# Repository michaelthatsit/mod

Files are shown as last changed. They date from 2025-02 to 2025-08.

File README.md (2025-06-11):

#  Adept Anyball

[Ploopy Adept](https://ploopy.co/adept-trackball) mod for 8 mm BOSCH Rexroth <a href='#btus-needed'>BTUs</a> with optional <a href='#magnets'>magnetically</a> attachable buttons. \
Various adapters are available, making it possible to use not just BTUs but also default ball bearings, static bearings. 



## Compatibility<sup>\*</sup>

| Ball | | |
| --- | --- | --- |
| 34 mm, 38.1 mm | ✔️  | e.g. Perixx, original Ploopy Nano ball; see [this repo](https://github.com/adept-anyball/ploopy-adept-small-btu) |
| 44 mm | ✔️  | e.g. from ProtoArc, JOMAA |
| 45 mm | ✔️  | default Adept ball |
| 50.8 mm | ✔️  | english pool ball, from Adesso T50 |
| 52.4 mm | ✔️  | snooker ball |
| 55 mm | ✔️  | e.g. from Kensington Expert, Perixx |
| 57 mm | ✔️  | pool ball |
| 60 mm | ✔️  | pool ball |
| 68 mm <sub>?!</sub> | ✔️  | russian<sup>\*\*</sup> pyramid ball |

<sup>\*chances are your ball is compatible if it's within the \[min, max\] range, and it probably is.</sup> \
<sup>\*\*kindly consider [supporting Ukraine](https://u24.gov.ua) to fight Russia in the ongoing invasion and occupation.

## General tips

> ❗️ **Important!** \
> \
> Use STL (not STEP) files for Slic3r forks, i.e. Prusa-, Orca-, Bambu Slicer. 
> STEPs are for CADs. There has been many cases reported when a STEP file has caused invalid geometry, 
> including critical changes such as "no gap between button and shell".

### Printing

1. There MUST be no supports, unless you really know what you are doing.

2. PLA, PETG, ABS — any of those are fine. 

### Other

1. Insert magnets on a flat hard surface while the device is not assembled.

2. Cyanoacrylate (superglue) works nice for magnets.

3. If you experience buttons sticking, try loosening the screws or removing the sensor cover.

4. If you experience bad tracking, you may want to print and install spacers.

## 57-68 mm ball (or 50-60 mm with spacers installed)

<p>
  
  
</p>

## 50-55 mm ball

Also available for non-standard BTUs: 
[SP-8](https://github.com/adept-anyball/mod/issues/5), [Veichu-15](https://github.com/adept-anyball/mod/issues/11).

> If you use CY-8H Aliexpress BTUs, it is recommended to go with the 50-52.4mm version instead. \
> You can ignore the fact that it is deprecated in such a case. \
> That version (in combination with this BTUs) should work with a 55 mm ball too.

<p>
  55mm ball
  55mm ball
</p>

## 50-55 mm ball (short version)

Fits a 50-55 mm ball. In this mod, the bottom and top parts of the original Adept case have been modified.

<p>
  55mm short top
  55mm short side
</p>

## 50-55mm ball (short, thin bezel)  
Fits a 50-55 mm ball. In this mod, the bottom and top parts of the original Adept case have been modified.  
It was built based on the short version above.
<div style="display: flex; justify-content: space-between; align-items: center;">
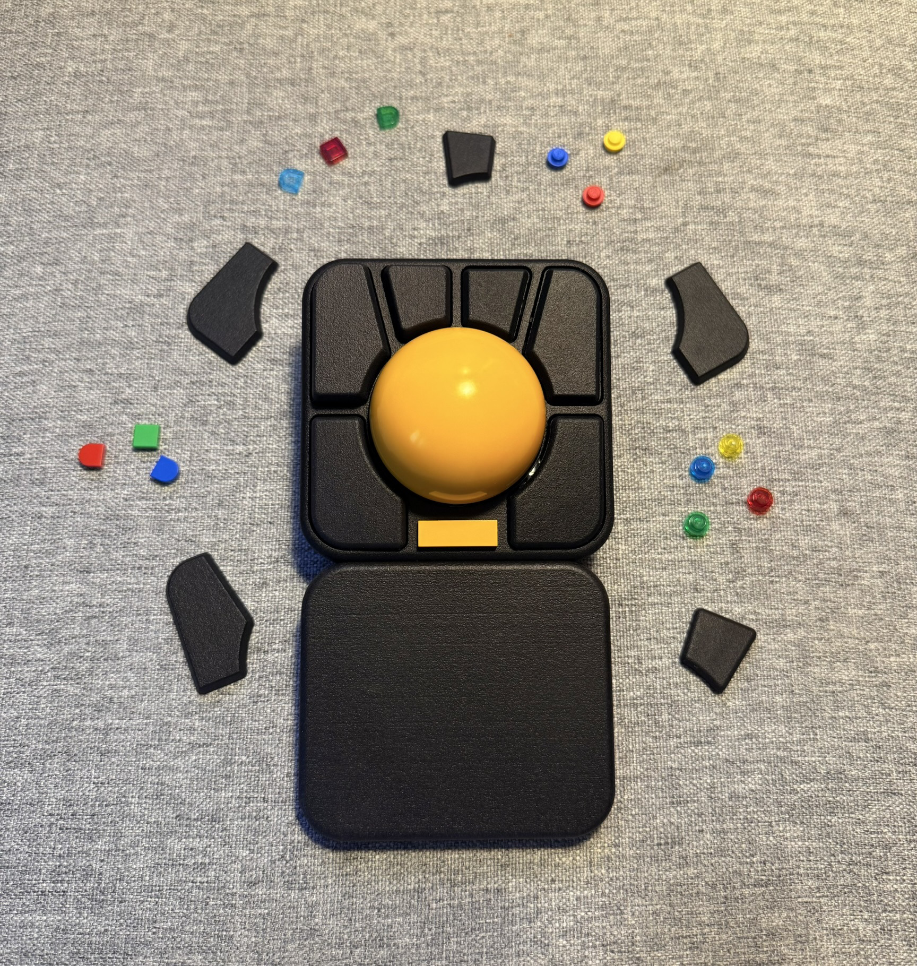
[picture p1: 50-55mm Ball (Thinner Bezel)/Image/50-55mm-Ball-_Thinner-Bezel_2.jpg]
Side View
  
  Close-up View
</div>

## 44-45 mm ball

This mod fits the original 45mm ball. \
You can find the 3MF files for Bambu printers on [Makerworld](https://makerworld.com/en/models/1087275#profileId-1080219).

<p>
  45mm top
  45mm top without ball
</p>

## 50-52.4 mm ball _DEPRECATED_

> The shell is deprecated, see 50-55mm one. It has standard size buttons and better BTUs placement.

<p>
  
  
</p>

## BTUs needed

[This is the link](https://store.boschrexroth.com/BALL-TRANSFER-UNIT_R053010810) to genuine BOSCH Rexroth BTUs.

<p>
  BTU specsheet
</p>

CY-8H BTUs from AliExpress [are compatible](https://github.com/adept-anyball/mod/issues/6), with one exception so far. \
[SP-8](https://github.com/adept-anyball/mod/issues/5) and [Veichu-15](https://github.com/adept-anyball/mod/issues/11) are not directly compatible, but there are model(s) available. \
Rexroth BTUs are clearly superior and are highly recommended.

## Magnets

You will need 4x2 mm circular neodymium magnets, full set (device + buttons) is 24pcs. \
They MUST be glued, ideally with a cyanocrylate based glue. 

## Quality Assurance

We have the best of the best.



## Even more photos

See [gallery](https://github.com/adept-anyball/mod/issues/7).

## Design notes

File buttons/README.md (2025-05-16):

# Buttons

The buttons in this folder are [ISO-2025EFOG](https://github.com/efogdev/ISO-2025EFOG) compliant and are compatible with the mods that follow the standard. The shape and size are absolutely identical to the default Ploopy buttons.

## Spherical 5mm

5 mm tall with a 2 mm deep spherical cut:

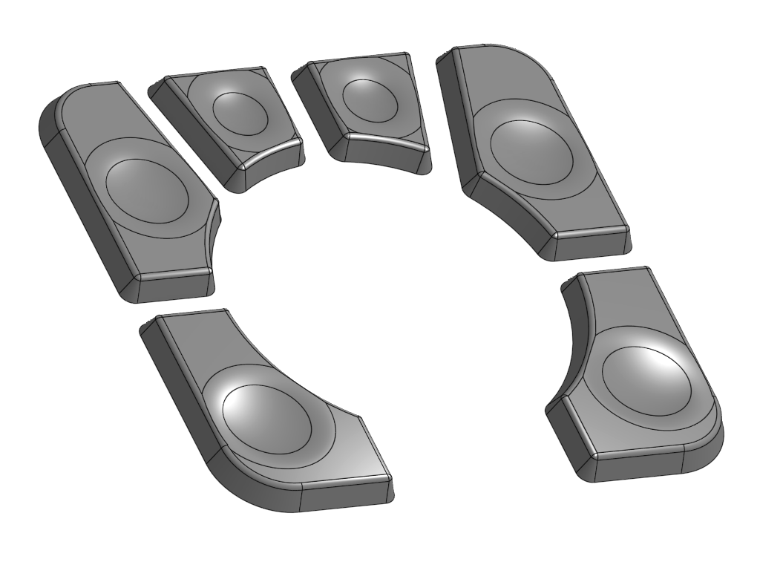
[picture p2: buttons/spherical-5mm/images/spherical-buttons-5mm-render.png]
spherical-5mm


## Flat 5mm

5 mm tall flat buttons

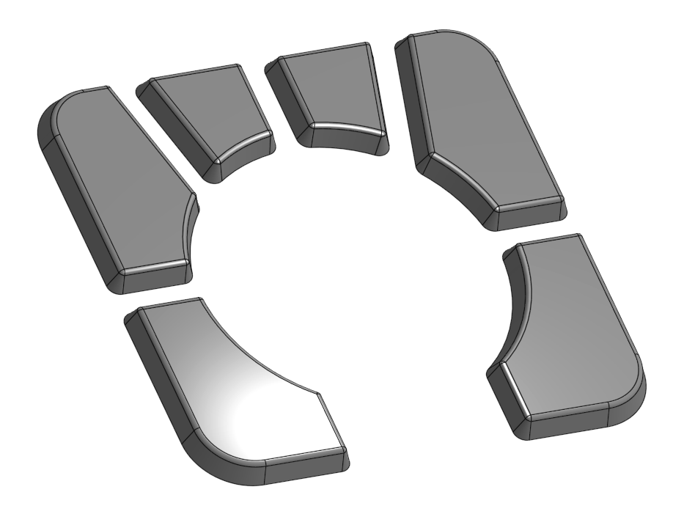
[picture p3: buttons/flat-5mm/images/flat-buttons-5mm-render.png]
flat-5mm


## Default

The default style buttons will look like this:



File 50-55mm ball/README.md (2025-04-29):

## Adept + 50-55mm ball

> ✅ [ISO-2025EFOG](https://github.com/efogdev/ISO-2025EFOG) compliant

> ❗️ It has been reported that CY-8H Aliexpress BTUs don't work with this version well. 

## Everything?

Everything. Even the sensor cover, the bottom part, the "default" buttons. \
**You need to split those in your slicer before printing.** \
The bottom part is optional and is 100% compatible with the default Ploopy bottom.

A [public third-party Onshape document](https://cad.onshape.com/documents/8ccfa9641ddd3f6929d9303b/w/a0d313c8d0288c4ecea783e6/e/e5fdbae89a3f2a2f05d6562c
).

## FAQ

Q: Layer height? \
A: Use 0.1-0.12mm for the buttons and 0.2mm for everything else.

Q: Where are other buttons? \
A: [Here](https://github.com/adept-anyball/mod/tree/master/buttons).

Q: I don't have magnets, is it usable? \
A: Yes, it is very usable even with magnets not inserted. 

Q: 57mm ball pretty please??? \
A: Might work with 0.4mm spacers. I haven't tried that. 

Q: Why is the bottom part even here? \
A: It is 1.2mm lower but has the sensor chip exposed. It is recommended to cover the hole with any tape. 

Q: top-for-non-standard-*-BTUs.stl \
A: Pretty self-explanatory, isn't it? You can also go to the issues to find a relevant thread. Please make sure to "split to object" in your slicer before printing.

## Demo



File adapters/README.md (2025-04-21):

## Adapters

This folder contains various adapters. \
Most work best with TPU, but PETG and PLA are also fine.

### Veichu

Allows Veichu 7.5mm BTUs to be used instead of Rexroth ones. \
Not recommended for >50mm balls. \
[Github issue](https://github.com/adept-anyball/mod/issues/4)

### Static

[Github issue](https://github.com/adept-anyball/mod/issues/8)

#### 3-3.5mm

Allows static bearings of size 3-3.5mm to be installed (with glue). \
Not recommended for heavy balls.

#### 2.5mm, 3mm and 3.5mm (no glue - 2 pieces)

Allows static bearings of 2.5mm, 3mm or 3.5mm to be installed (choose the correct file according to the size of the bearing)

> This adapted consists of 2 parts, so make sure to split it in your slicer. \
> This adapter requires no supports to be printed. \
> The 3mf for the 2.5mm is included too, if you have a Bambu Labs printer. It is recommended to print with a layer height of .1mm and width of .3mm, since the parts are small.

> **DISCLAIMER: Since I don't have any 3mm or 3.5mm static bearing at hand, then these 2 models are untested for the time being.**

To use it, insert the bearing ball in the bottom of the adapter. Slide the bottom part in the top part and turn the bottom to lock.

<p>
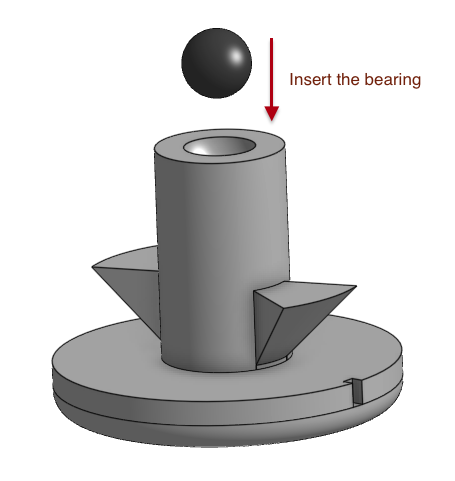
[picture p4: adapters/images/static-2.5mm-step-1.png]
  
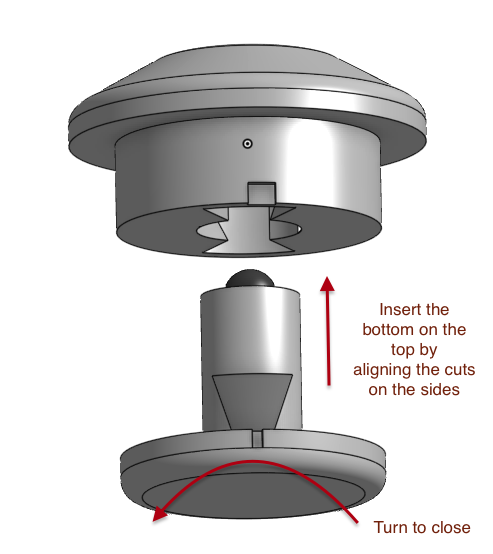
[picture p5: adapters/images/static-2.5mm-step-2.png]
  
</p>

### MR63 ball bearings

Allows default Ploopy MR63 ball bearings to be installed. \
[Github issue](https://github.com/adept-anyball/mod/issues/22)

## Notes

Please print adapters oriented like this:



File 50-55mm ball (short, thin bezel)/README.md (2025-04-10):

 # 50-55mm ball (short, thin bezels)
50-55mm Ball Side Preview
> ✅ [ISO-2025EFOG](https://github.com/efogdev/ISO-2025EFOG) compliant

This mod is an adaptation of the original case where the top and bottom of the original adept are changed. The optics cover (bottom of the top case) is the same as the original.
The mod is designed for a 55mm ball, but works with 50-55mm balls.

> Note from [@efogdev](https://github.com/efogdev): \
> This is a community contribution from [@Dexter-KBD](https://github.com/Dexter-KBD).
> As the owners of the Anyball repo can't directly provide support with this variant,
> please make sure to tag [@Dexter-KBD](https://github.com/Dexter-KBD)
> when creating an issue/discussion related to it.

Disclaimer
====================
Since English is not my native language, this post was translated with the help of ChatGPT. Thank you for your understanding.
If there's anything unclear or if you have any questions, feel free to join [Ploopy Discord channel](https://discord.com/invite/qYK9psKrNY)
 and ask anytime.

<br>

About This Model
====================
50-55mm Ball Preview

This design is a modified version based on the 55mm short version originally created by [@fabriciobastian](https://github.com/fabriciobastian)
  
I’d like to express my sincere thanks to [@fabriciobastian](https://github.com/fabriciobastian) for creating such a great model.  
[50-55mm ball (short version)](https://github.com/adept-anyball/mod/tree/master/50-55mm%20ball%20(short%20version))  

BOSCH Rexroth BTUs must be used. 
I haven't tried anything else, but looking at users' reviews, it's terrible. Buy BOSCH Rexroth BTUs. 
I bought it on [this site](https://www.robaraindustries.com/en/product/42563/ball-transfer-units-r053010810-ku-b8-ofk-rex.html)
 (it took me 3 weeks with the cheapest shipping option)
<br>

About the LEGO-Compatible Case
====================
The case with LEGO brick mounts was designed specifically for 3D printing using PA12 MJF material.
This structure relies on MJF’s powder-based printing method to be printed properly.
(If you're not sure what that means, I recommend watching a YouTube video showing how MJF printing works.)

Because of this, using this file with FDM printing will require support structures.
Since I don’t have in-depth knowledge of 3D printing, I wasn’t able to figure out a way to print this model without supports.
So, I have also included a modified version optimized for FDM printing that does not require support.
<br>

FDM-Specific Versions
====================
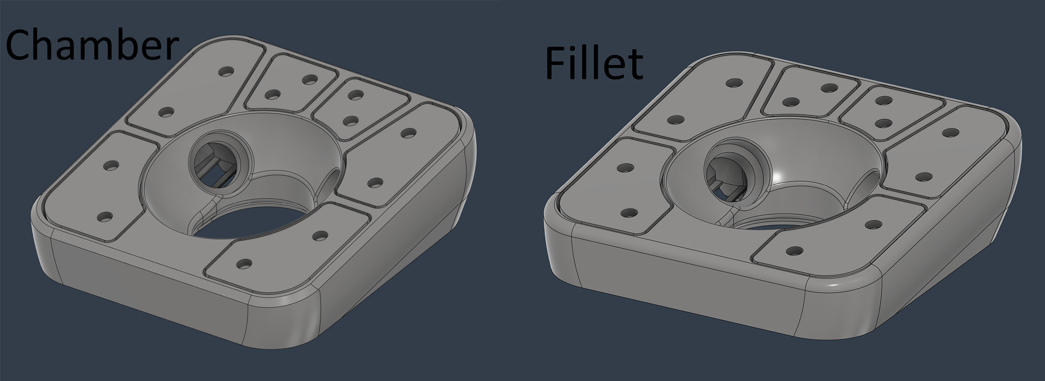
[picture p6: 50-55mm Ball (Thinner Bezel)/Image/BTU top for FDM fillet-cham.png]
BTU Top for FDM (Fillet/Chamfer)


To help ensure better print quality with FDM, I’ve included two versions:
one with chamfered corners and one with filleted edges.
I haven’t tested which one prints better, so it’s entirely up to you to choose.
<br>

Spring Adjustments for MJF
====================
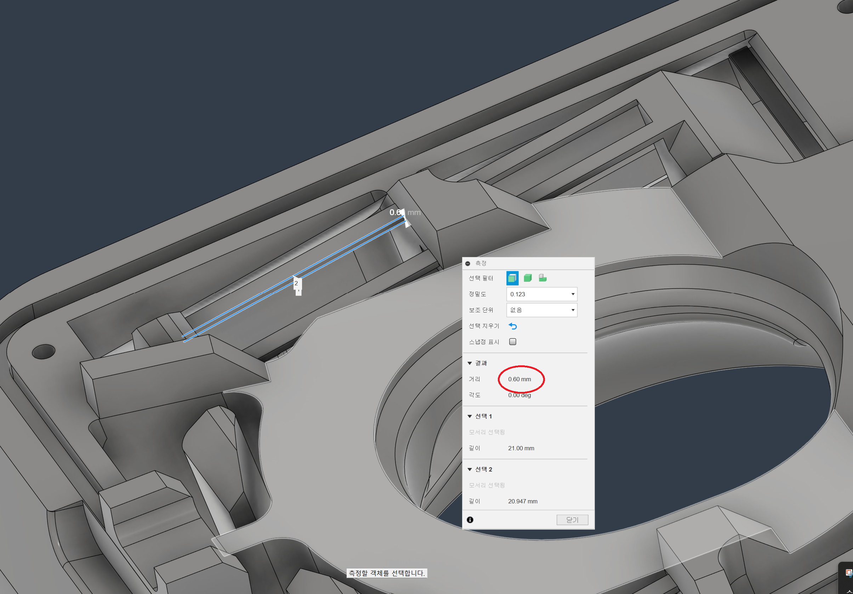
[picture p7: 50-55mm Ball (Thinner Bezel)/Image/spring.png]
Spring Detail


Since MJF materials are more flexible, I’ve increased the thickness of the button spring from 0.6mm to 1.2mm.
There are also a few other minor adjustments to help prevent damage during MJF post-processing.
<br>

FDM Version Details
====================
The FDM version keeps the original 0.6mm spring design.
Also, the pillar that holds the LEGO brick was removed to allow the surface to be printed facing down, resulting in better quality.
<br>

Palm Rest (Bonus)
====================
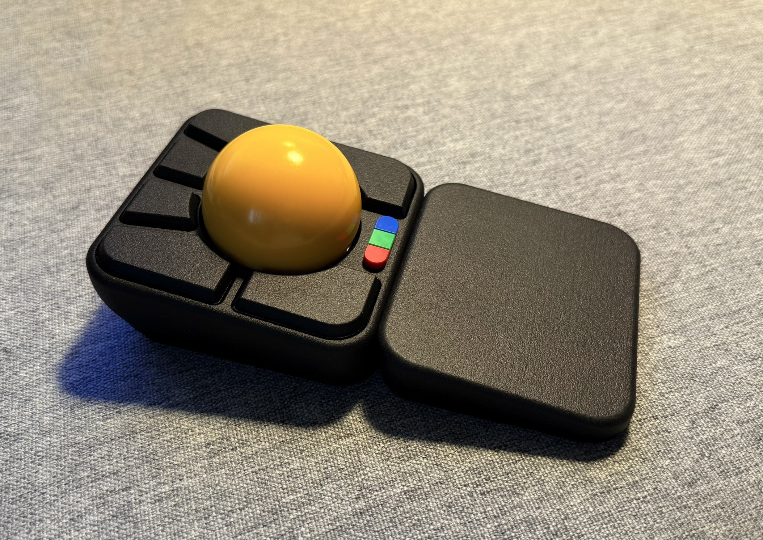
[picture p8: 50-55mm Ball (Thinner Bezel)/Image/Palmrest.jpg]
Palmrest Preview

I’ve also included a palm rest, just in case anyone finds it useful.
It was a quick 10-minute design, so I wasn't sure whether to share it, but I uploaded it anyway.
Since it was printed with MJF, there is a hole at the bottom.

It can be too short or too narrow because it's tailored to my hand.  
Make sure to check the size.  
It measures 92.7mm by 79mm.  
The height matched the case.  
<br>

Final Note
====================
Once again, please note that I have never printed this model using FDM materials.
This version simply shares the same design with a modified 0.6mm spring thickness.
Unexpected issues may arise.
If you enjoy experimenting, feel free to try printing with my file.
But if you prefer a well-tested and stable version, I recommend using one of the existing mods.
  
Thank you!

50-55mm Ball Close-up

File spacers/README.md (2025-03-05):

## BTU Spacers

> Works best with TPU. PLA/PETG is fine too.

Possible reasons to print a spacer or several:
1) Your ball touches the shell while rolling.
2) You want to use a smaller ball than the shell allows.
3) Your particular ball doesn't work well even though the shell supports it's size.

In either case, spacers may help. Or may not. Example usage:



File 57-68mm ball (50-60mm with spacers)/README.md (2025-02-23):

## Adept + 57-68 mm ball

> ❗️ not [ISO-2025EFOG](https://github.com/efogdev/ISO-2025EFOG) compliant

## Spacers

You need spacers for 50-56.5mm balls, see the README in the directory.

## FAQ

Please refer to [the README](https://github.com/adept-anyball/mod/tree/master/50-52.5mm%20ball%20(deprecated)/README.md) for 50-52.5 mm ball. \
Main differences: there is no smooth version, there is no version without magnets (I don't think it makes sense). \
The recommended buttons are D850 Hn6 (Hn = H<sub>negative</sub>, see [this README](https://github.com/adept-anyball/mod/blob/master/buttons/default/README.md)). 
> Tip: scale the logo in slicer if it doesn't fit. \
> Extra tip: print logo parts in several sizes (95%, 100%, 105%) as the shell has holes to extract those and you can switch ±easily (you still need to disassemble the Adept tho).

## Demo





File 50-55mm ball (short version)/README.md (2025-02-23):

# Adept 50-55mm ball (short version)

<p>
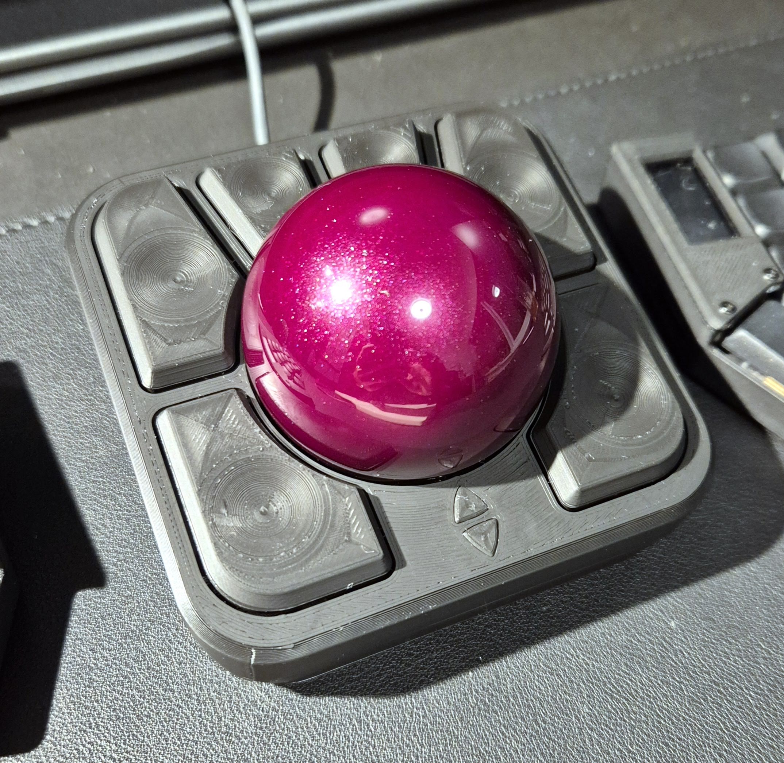
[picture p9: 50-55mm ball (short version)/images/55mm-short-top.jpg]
55mm short top
  
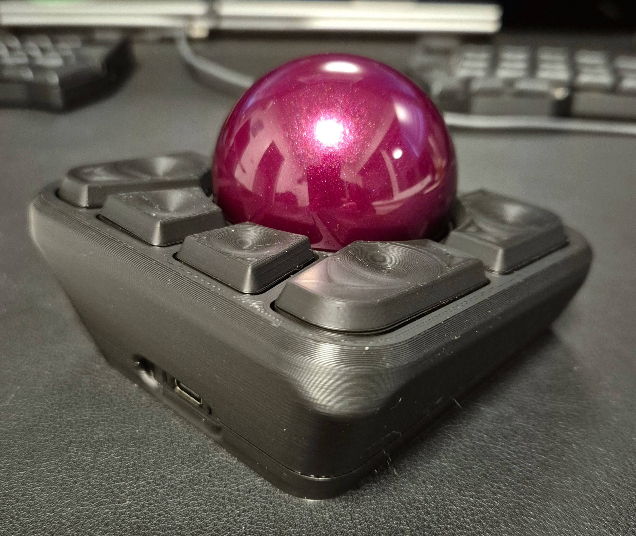
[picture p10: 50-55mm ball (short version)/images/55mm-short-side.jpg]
55mm short side
  
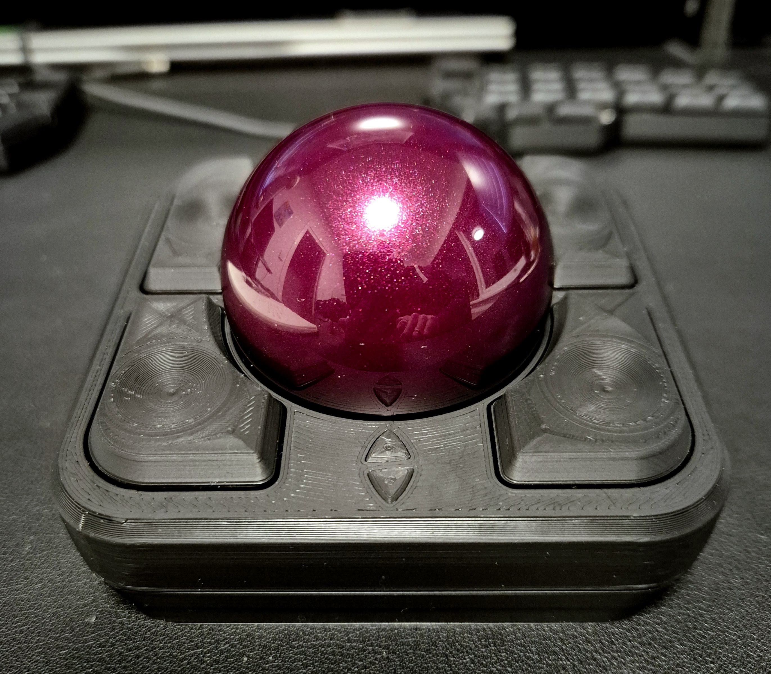
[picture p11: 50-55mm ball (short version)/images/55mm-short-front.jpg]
55mm short front
  
</p>

> ✅ [ISO-2025EFOG](https://github.com/efogdev/ISO-2025EFOG) compliant

This mod is an adaptation of the original case where the top and bottom of the original adept are changed. The optics cover (bottom of the top case) is the same as the original.
The mod is designed for a 55mm ball, but works with 50-55mm balls.

The following files are available in both STEP and STL:

- top-short-55mm: the top of the case without magnet holes
- top-short-55mm-magnets: the top of the case with magnet holes
- bottom-short: the bottom of the case. The bottom of the short mod is the same for the 55mm and 45mm, it is just available here too for convenience
- logo-insert-short: insert for the logo. It can be printed in different colors, if desired

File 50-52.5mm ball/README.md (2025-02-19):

## Adept + 50-52.5 mm ball

> ❗️ not [ISO-2025EFOG](https://github.com/efogdev/ISO-2025EFOG) compliant

## FAQ
Q: `rev1` or `rev2`? \
A: `rev2` 

Q: What does "50-52.5 mm" mean? \
A: `rev1` is compatible only with 50 mm ball, `rev2` should work with any diameter within the range.

Q: What's with the "bottom" and "sensor-cover"? \
A: Sensor cover is required to print. Bottom is the bottom part but slightly lower, it is optional.

Q: Can I print "magnets" version if I don't have magnets yet? \
A: Yeah it actually is very usable even with magnets not inserted.

Q: Do I need to populate all the 11 magnets for the wrist rest? \
A: I believe 5 should be enough. You can try as low as 3 tho.

Q: STEP or STL? \
A: I recommend using STL for slicer and STEP for CAD.

## Layer height
1. Top (Smooth), buttons, wrist rest: 0.1-0.12 mm
2. Top (Sharp), other: 0.1-0.2 mm

## `Flat` vs `Magnets`
Flat version is just like the default one. \
The one marked as "magnets" includes slots for magnets to attach raised buttons and wrist rest. \
Magnets required: 4x2 mm, 24 pcs for the buttons and 3/5/7/11 pcs for the wrist rest. \
Demo with buttons attached: 



## `Sharp` vs `Smooth`
55mm

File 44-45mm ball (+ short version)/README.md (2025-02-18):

## Adept + 44-45mm ball

> ✅ [ISO-2025EFOG](https://github.com/efogdev/ISO-2025EFOG) compliant

Q: Layer height? \
A: 0.2 mm

Q: What is the standard mod? \
A: It is the original case modified top fit the BTUs. All you need is to reprint the top part. For more info, see [here](./standard/README.md).

Q: What is the short mod? \
A: It is a slightly smaller mod, where both the top and the bottom of the case are changed. The blank space at the end of the top of the original case is remove, and the bottom part is aligned with the top (in the original it is smaller). \
For more info, see [here](./short/README.md). \
This is how it looks: \
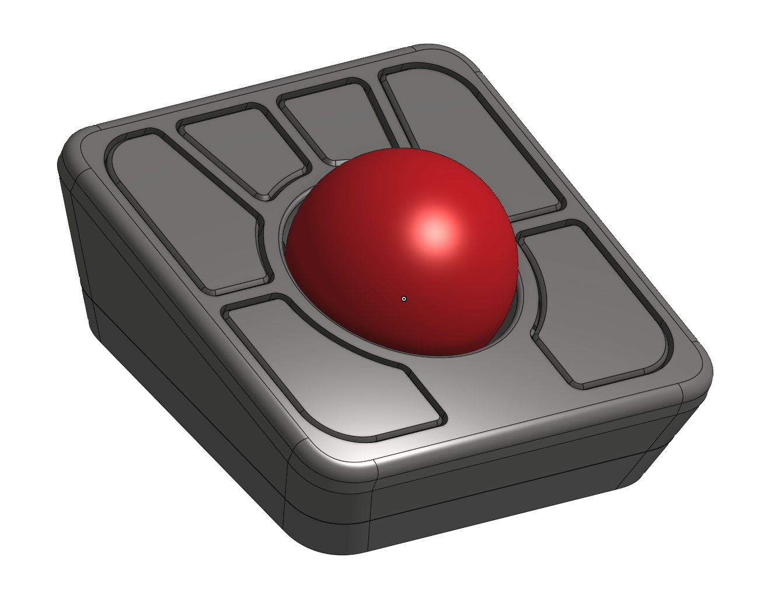
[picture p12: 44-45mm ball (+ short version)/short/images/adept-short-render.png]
45mm short


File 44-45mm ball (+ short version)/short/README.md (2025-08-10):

# Adept 44-45mm short mod

This model is changes both the top and the bottom of the case. The optics cover it still compatible with the original one.
The main differences from this mod and the original case is that it is slightly shorter and the top and bottom are aligned. In the original model, the bottom is smaller then the top. The case is designed to fit the original 45mm pool ball, but it should also work with a 44mm ball.

45mm short

The following models are available here:

- bottom-short-45mm: the bottom of the case
- top-short-45mm-magnets: the top part of the case with holes for the 4x2mm magnets and complies with ISO-2025EFOG
- top-short-45mm: the top of the case without any holes for magnets

Both models have STEP and STL files for you to choose between.

## AdeptBLE Short

This version is modified to support the [adept BLE mod](https://github.com/taichan1113/AdeptBLE). It includes room for a battery and a convenient switch hole and cover.

the battery cavity was shaped to [fit this battery](https://www.amazon.com/dp/B095VW1RB8?ref=ppx_yo2ov_dt_b_fed_asin_title&th=1) which can be found on amazon.

The top was modified slightly to avoid pressing down on the pins soldered into the board.

the following models are meant for the adept BLE short:

- bottom-short-battery: included the bottom plate and switch cover
- top-short-battery: includes the slightly modified top

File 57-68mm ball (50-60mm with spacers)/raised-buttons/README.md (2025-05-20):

## Buttons

Please see [this README](https://github.com/adept-anyball/mod/tree/master/buttons/default) for explanation.

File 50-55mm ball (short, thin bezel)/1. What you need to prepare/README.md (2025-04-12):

# Beginner Guide: What You Need to Prepare for the Ploopy Adept Mod

## 1. Ploopy Adept PCB
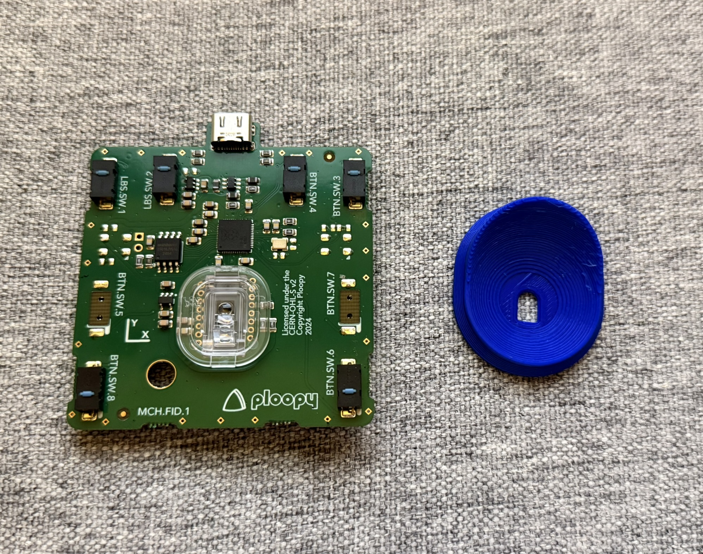
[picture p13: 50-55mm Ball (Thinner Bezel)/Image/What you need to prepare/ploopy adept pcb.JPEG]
Ploopy Adept PCB
   

You can either purchase a [fully assembled version](https://ploopy.co/shop/adept-trackball-fully-assembled/)
 from the official Ploopy website or build one yourself using the [open-source files](https://github.com/ploopyco/adept-trackball/tree/master/hardware/electronics)
. If you're a beginner and unfamiliar with soldering or hardware, I recommend buying the prebuilt version. If you're an experienced builder, you probably don’t need my advice.

## 2. Case for the Mod
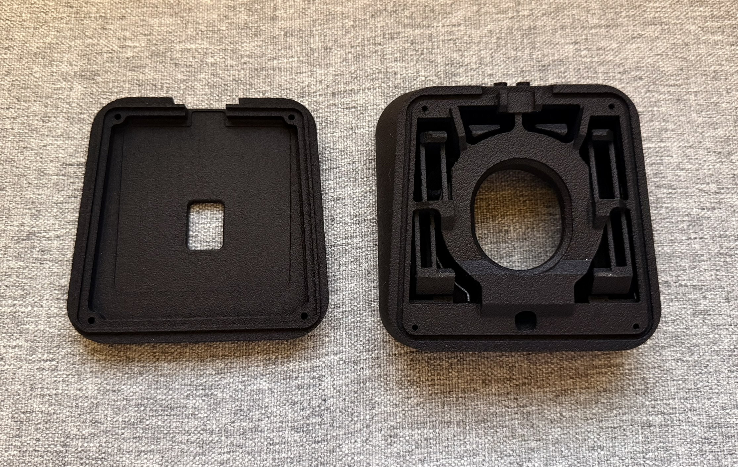
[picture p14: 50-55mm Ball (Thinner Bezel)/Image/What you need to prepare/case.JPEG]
Case for the Mod


You need only the top and bottom parts. The original sensor cover is reused. If you're not buying the prebuilt version from the official site and are instead building your own PCB, you will also need the sensor cover. (It's mainly for dust protection, so the device will still function without it.)

## 3. Buttons
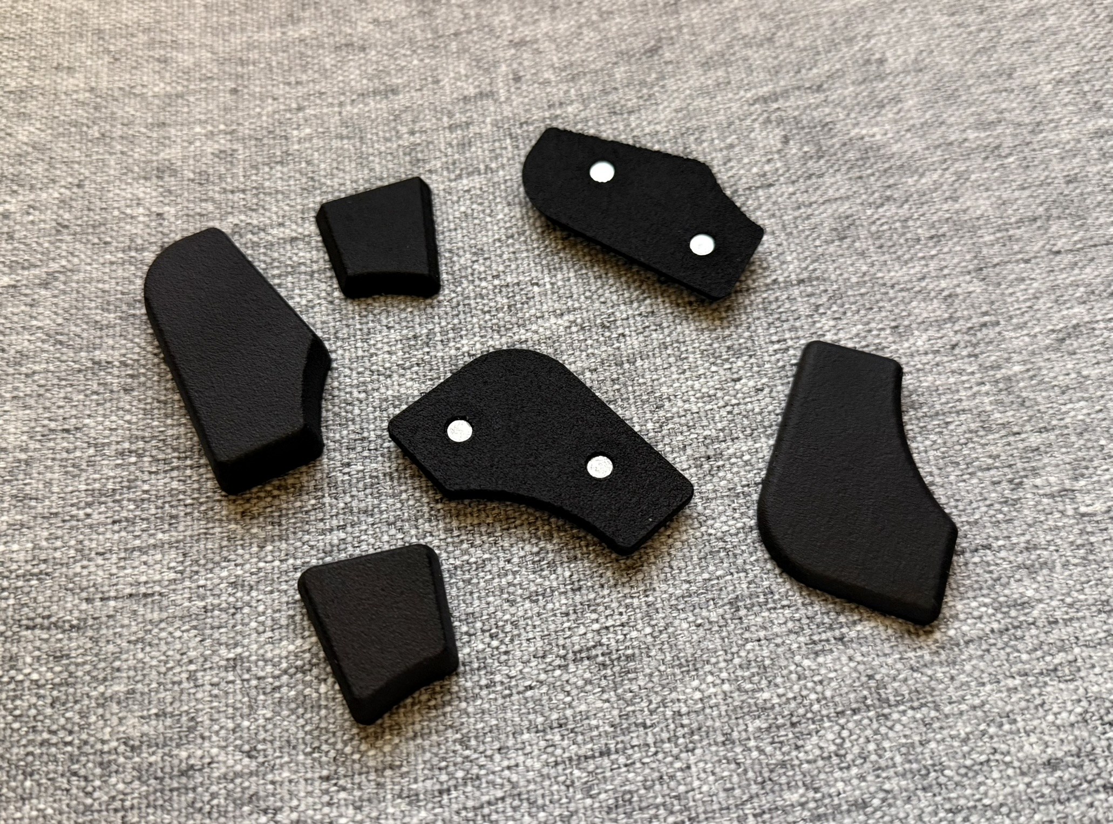
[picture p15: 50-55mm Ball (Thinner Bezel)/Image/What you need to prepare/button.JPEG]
Button Options


Choose buttons that fit your hand and print them. [Here's a link](https://github.com/adept-anyball/mod/tree/master/buttons)
 with various button options. The best approach is to use the original Adept buttons, get used to how the trackball works, and then determine which height suits each button. Note: if you're using the 55mm mod, the trackball sits higher, so the back buttons need to be taller. I recommend printing extras in different heights to test. The linked files already include buttons of different heights and angles.
I printed both the case and buttons using PA12 MJF at JLC3DP. I'll explain how to order from them below.

## 4. Magnets
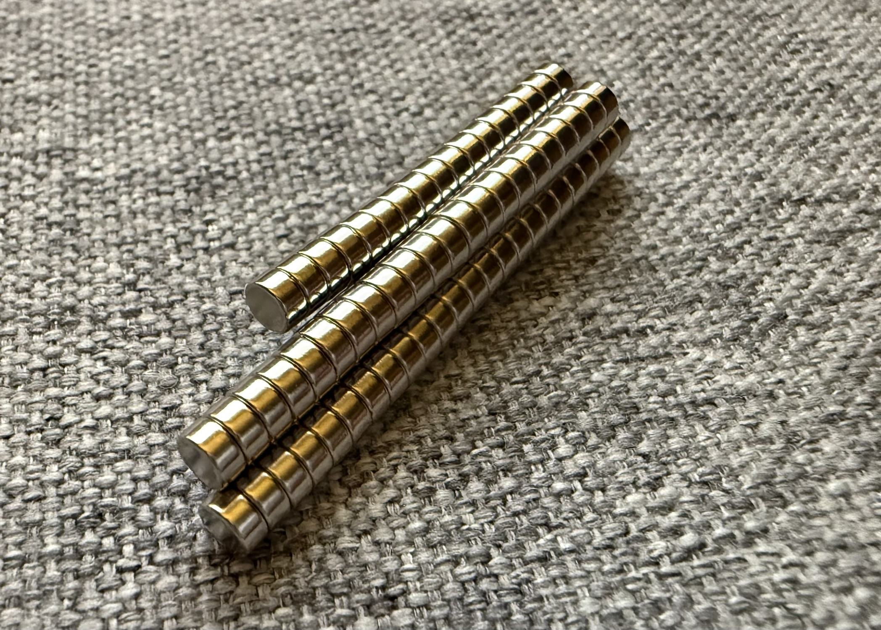
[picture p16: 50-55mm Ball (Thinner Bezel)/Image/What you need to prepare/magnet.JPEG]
Magnets


You’ll need round magnets with 4mm diameter and 2mm height for the case and buttons. Some cheap magnets may be only 1.7mm thick. Try to find ones that are closer to 2mm based on product reviews. 1.7mm still works, but if you want stronger attachment, go for 2mm. I bought mine from [Taobao](https://item.taobao.com/item.htm?_u=b206uqikd120b5&id=625305954944&spm=a1z09.2.0.0.7f582e8dCcXpoh)
, but Amazon or local hardware stores should have them too.

## 5. BTUs (Ball Transfer Units)
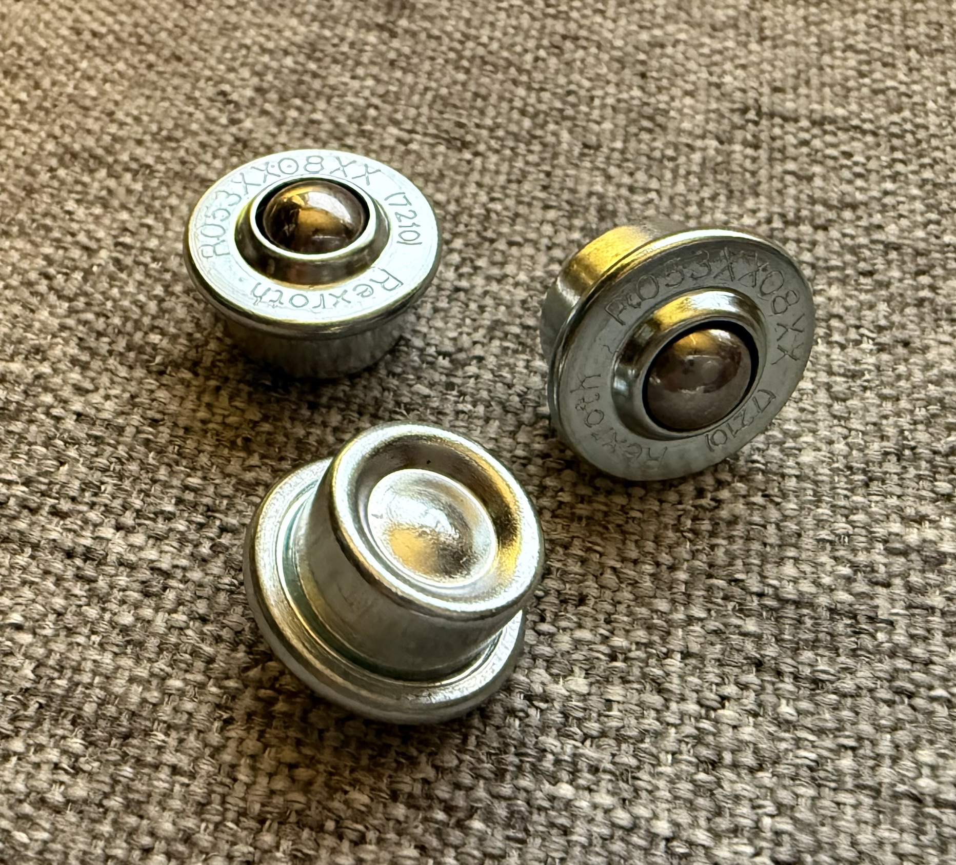
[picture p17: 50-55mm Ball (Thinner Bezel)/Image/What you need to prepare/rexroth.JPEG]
Rexroth BTU


Use the [Rexroth](https://www.robaraindustries.com/en/product/42563/ball-transfer-units-r053010810-ku-b8-ofk-rex.html)
 brand. I do not recommend other brands. Over 90% of the mod’s quality depends on the BTU. You can use alternatives, but I haven’t tested them—so issues may arise. Discuss in the Discord if you want to know more. If Rexroth is available in your country, please use it. I [ordered mine](https://www.robaraindustries.com/en/product/42563/ball-transfer-units-r053010810-ku-b8-ofk-rex.html)
 from a supplier with the cheapest shipping, which took 3 weeks, but it arrived safely.

## 6. Ball
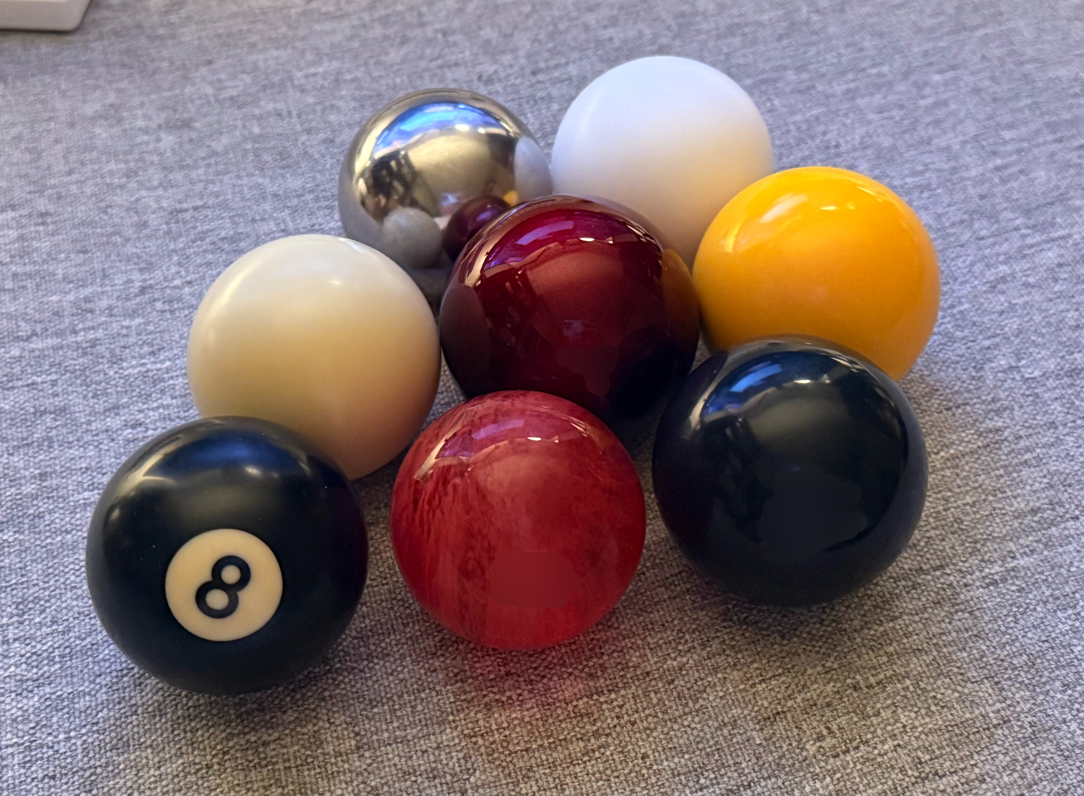
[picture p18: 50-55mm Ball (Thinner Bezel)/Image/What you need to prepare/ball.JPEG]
Ball Example


You cannot use the original 45mm ball. Prepare a 50–55mm ball instead. I'm currently using a [52.5mm snooker ball](http://item.taobao.com/item.htm?_u=b206uqikd1f786&id=716787460543&spm=a1z09.2.0.0.7f582e8dCcXpoh)
 and a [55mm Sanwa trackball](https://item.taobao.com/item.htm?_u=b206uqikd1fe7f&id=724775117995&spm=a1z09.2.0.0.7f582e8dCcXpoh)
, both of which work great.

## 7. Palm Rest (Optional)
When using the original Adept, I didn’t need a palm rest. However, the BTU mod raises the height and makes the ball much smoother, which made precise control harder without wrist support. I designed and shared a palm rest that fits my hand. Printing with MJF isn’t cheap, so feel free to explore cheaper alternatives like wood or acrylic.

## 8. Anti-slip Bumpers (Optional)
The bottom of the case has small holes designed for bumpers to prevent sliding. Depending on your desk surface, you might not need them. But I included the option. If needed, use bumpers no larger than 9mm in diameter.

## 9. Adhesive for Magnets
You don’t have to use super glue, but you'll need something to attach the magnets to the case and buttons.

## 10. Screws
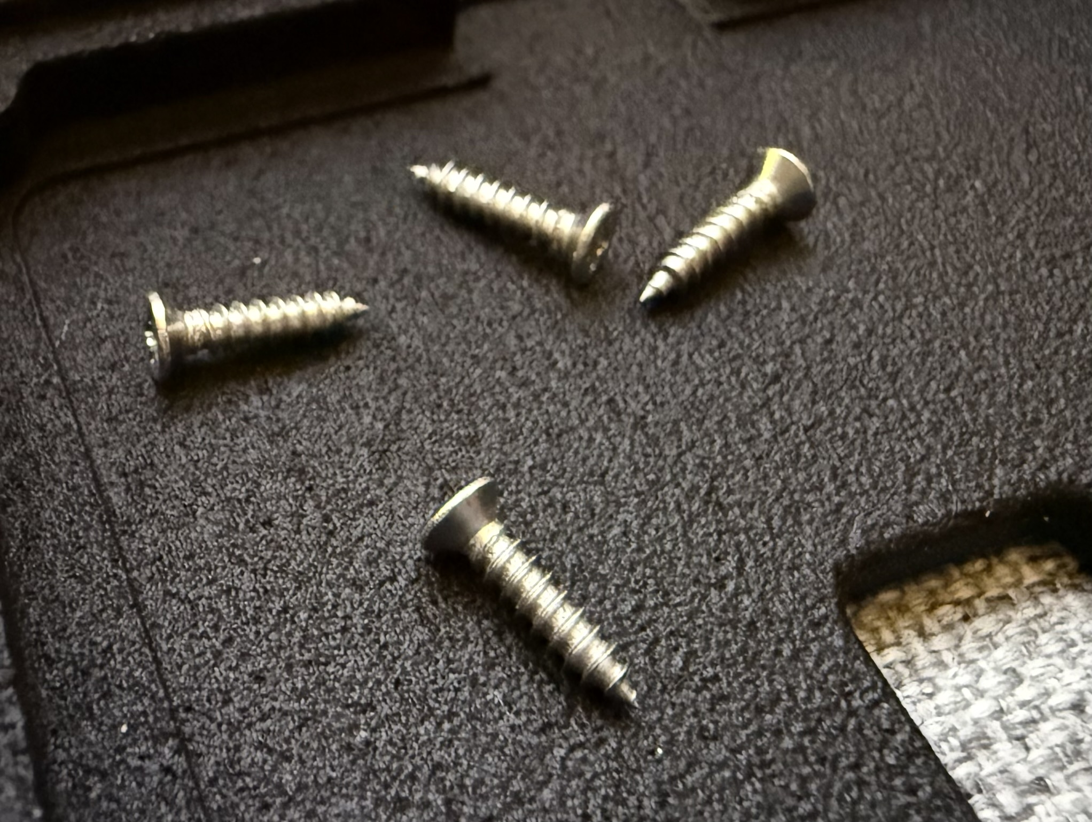
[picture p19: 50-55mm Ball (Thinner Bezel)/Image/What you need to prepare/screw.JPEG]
Screws


You can reuse the screws from the original Adept. If you need more, use #2 3/8" screws. I personally used [M2.2 9.5mm screws](https://item.taobao.com/item.htm?id=589373168768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)
.

## 11. LEGO Bricks
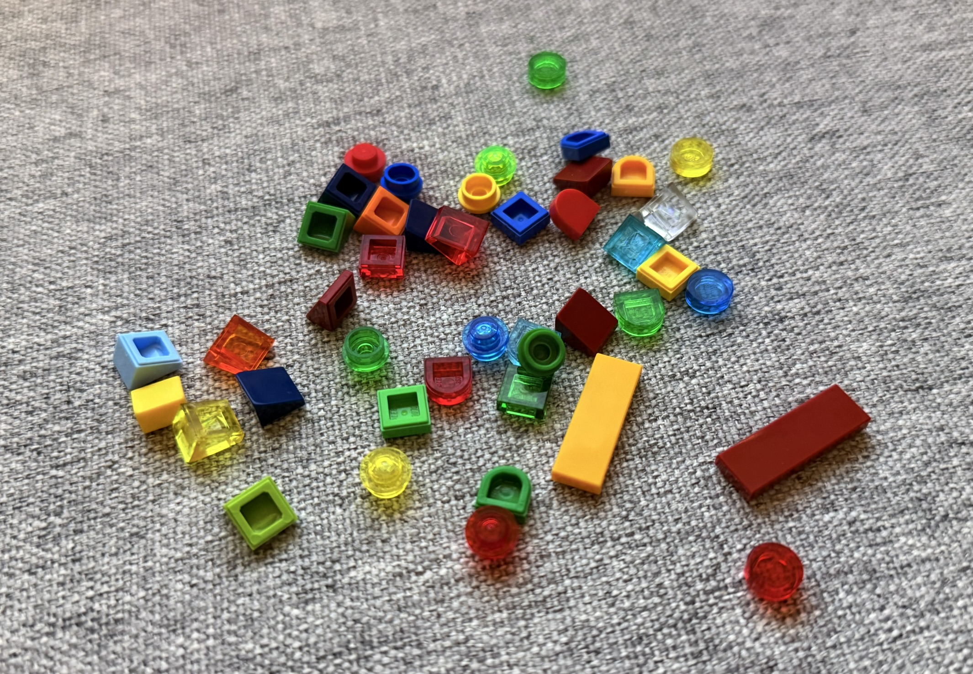
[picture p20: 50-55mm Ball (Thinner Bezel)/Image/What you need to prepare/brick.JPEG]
LEGO Brick


Yes, you’ll need a LEGO brick to fit into the 6 o’clock position of the case. Prepare a few small ones (1x1 or 1x3 size).
<br><br><br>

# How to Order from JLC3DP

You’ve probably already downloaded the required files. [Go to the site](https://jlc3dp.com/3d-printing-quote?spm=Jlc3dp.Homepage.1011.d1)
, log in, and drag & drop the files. STEP or STL files are both fine. I uploaded STEP files (STL versions were shared upon user request).
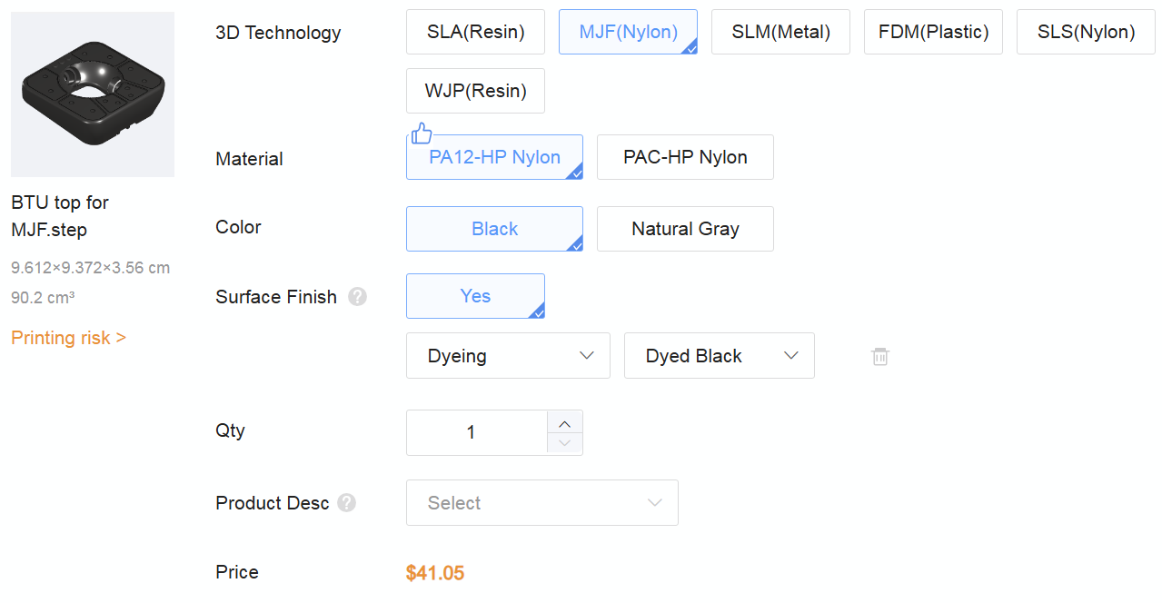
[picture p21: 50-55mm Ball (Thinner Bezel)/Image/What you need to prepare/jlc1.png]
JLC3DP Upload Screenshot


Select the same options as shown in the image.
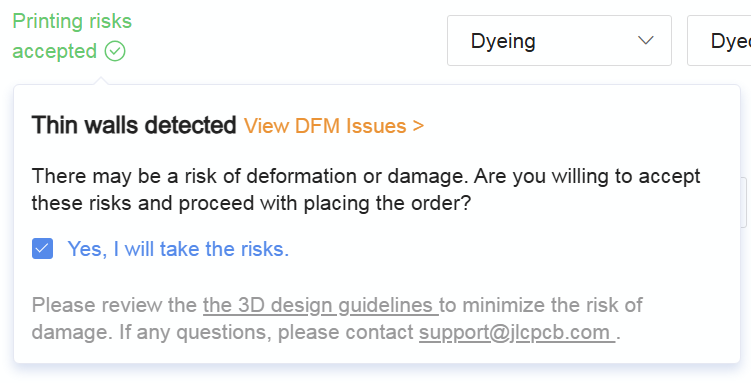
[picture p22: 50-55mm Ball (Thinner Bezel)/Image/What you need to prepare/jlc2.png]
JLC3DP Options


Be sure to check the box for accepting thin wall risks. It's usually not an issue. In my first prototype (0.9mm thickness), one button spring broke. Now I’ve improved it to 1.2mm, so the risk is lower.

Even if you check the box, JLC may still email you for confirmation regarding thin walls. Just confirm and proceed.

Yes, MJF isn’t cheap. But compared to FDM PLA, it guarantees much better surface quality. If you're curious about the types of 3D printing, I recommend watching some YouTube videos or doing a bit of research. Each printing method has its pros and cons—too much to cover here.
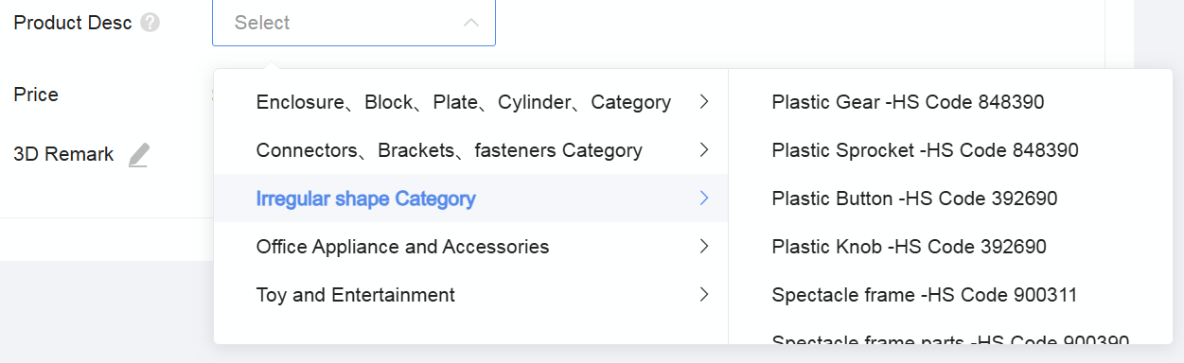
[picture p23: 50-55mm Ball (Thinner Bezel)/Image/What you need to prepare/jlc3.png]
JLC3DP Confirmation


Select “Product Desc” when ordering. It’s for customs in your country. You don’t need to match my screenshot exactly. These parts aren’t banned, so you don’t need to worry.

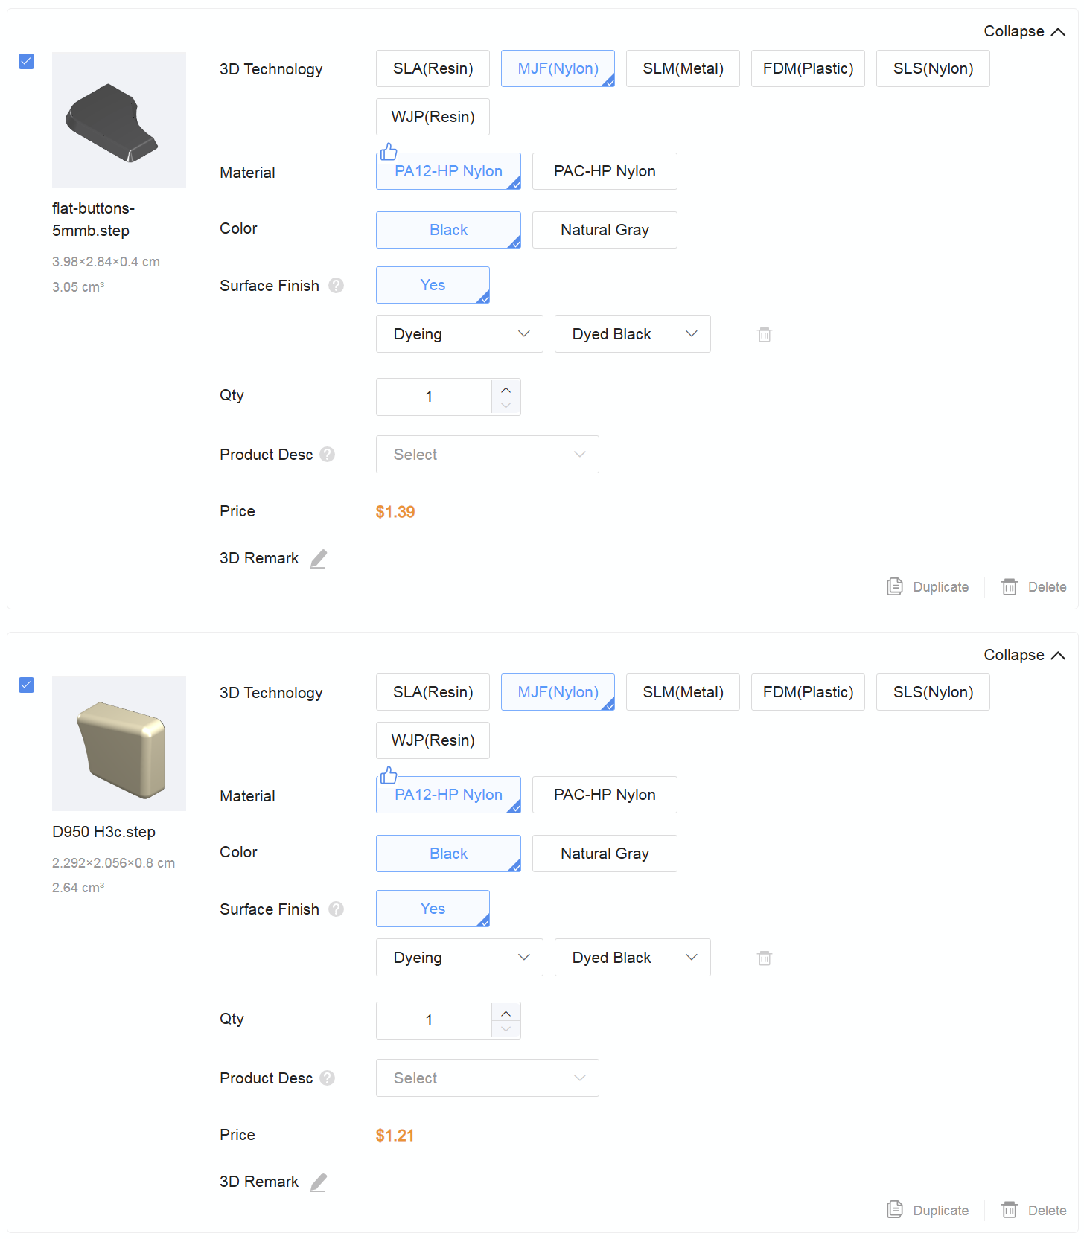
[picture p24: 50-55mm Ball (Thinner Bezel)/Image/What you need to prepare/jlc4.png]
JLC3DP Product Desc
For buttons: prepare each button as a separate file or merge them manually.
 Orders with multiple shells in one file will be rejected. If you’re a beginner reading this, just export one button at a time as a STEP file and only print what you need.

Double-check everything before placing your order.
JLC engineers will review your files before production. As mentioned, if there are thin walls, you’ll get a confirmation email. Be sure to reply, or the order won’t proceed.

Since manufacturing is done in China, I’m not sure how current US import tariffs may affect you hopefully there won’t be any additional cost.

Once the package arrives, your preparation is complete.  
See you in the assembly guide!

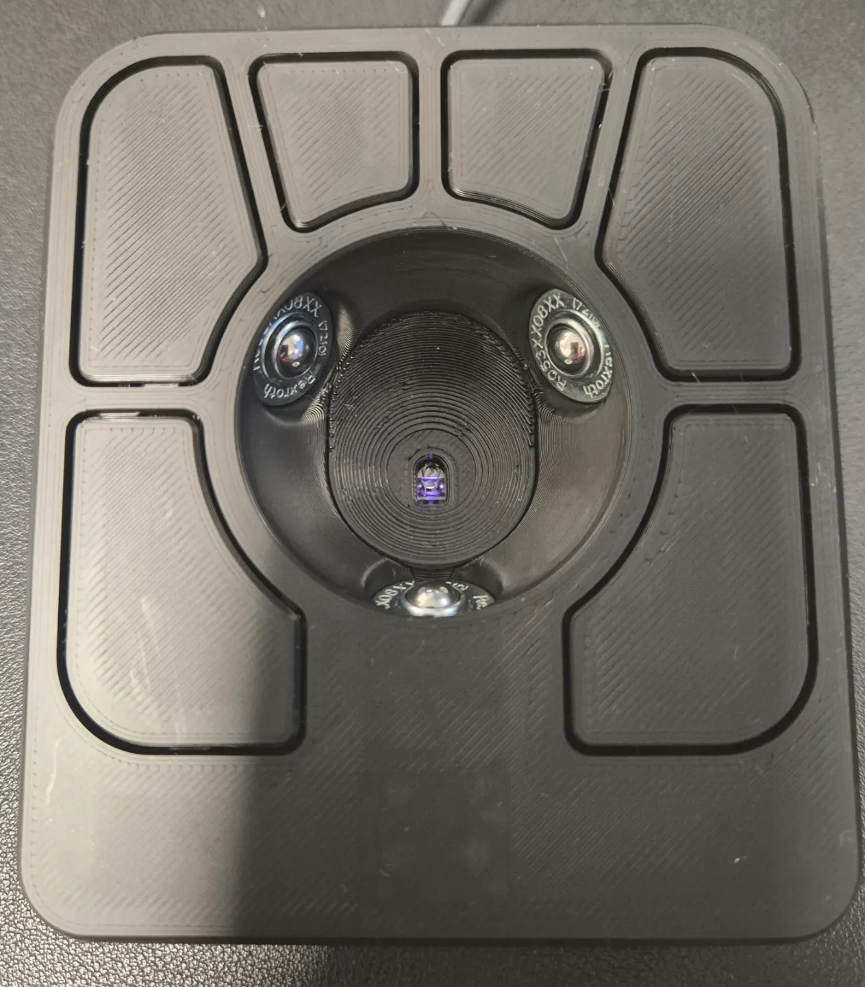
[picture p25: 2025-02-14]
44-45mm ball (+ short version)/standard/images/45mm-top-no-ball.png

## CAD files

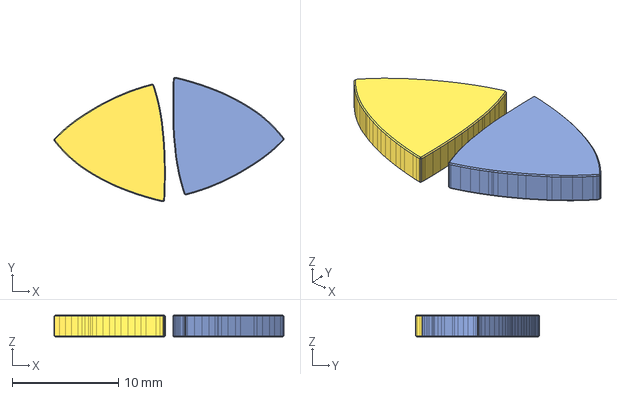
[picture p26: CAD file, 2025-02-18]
logo/Logo (Full).step
21.7 x 11.7 x 2.05 mm

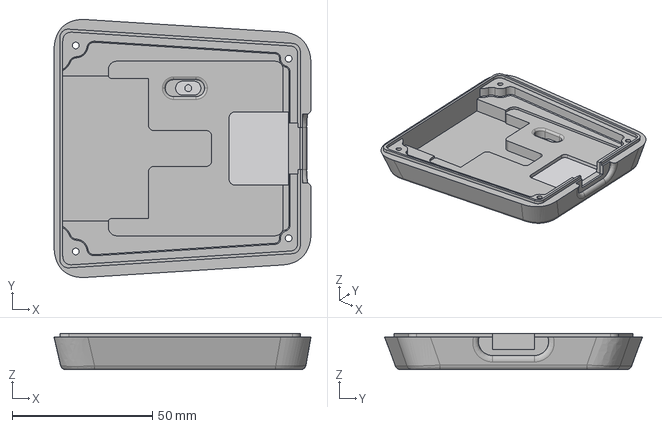
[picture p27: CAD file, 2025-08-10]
44-45mm ball (+ short version)/short/bottom-short-battery.step
91.6 x 91.9 x 13.0 mm

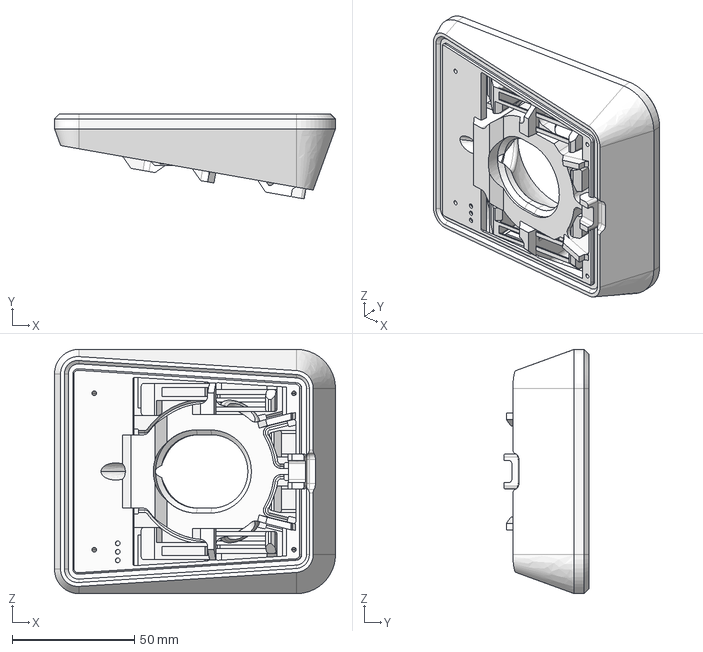
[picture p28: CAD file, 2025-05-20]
44-45mm ball (+ short version)/standard/top-45mm-magnets.step
115.0 x 34.7 x 100.0 mm

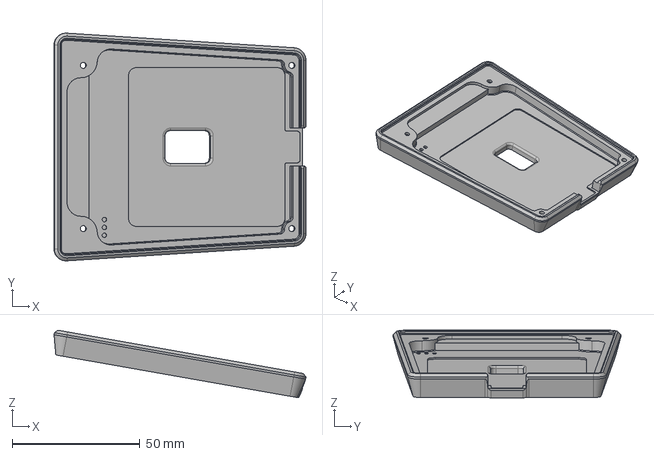
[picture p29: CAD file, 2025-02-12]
50-52.5mm ball/rev 2/bottom/Bottom.step
98.8 x 89.3 x 26.5 mm

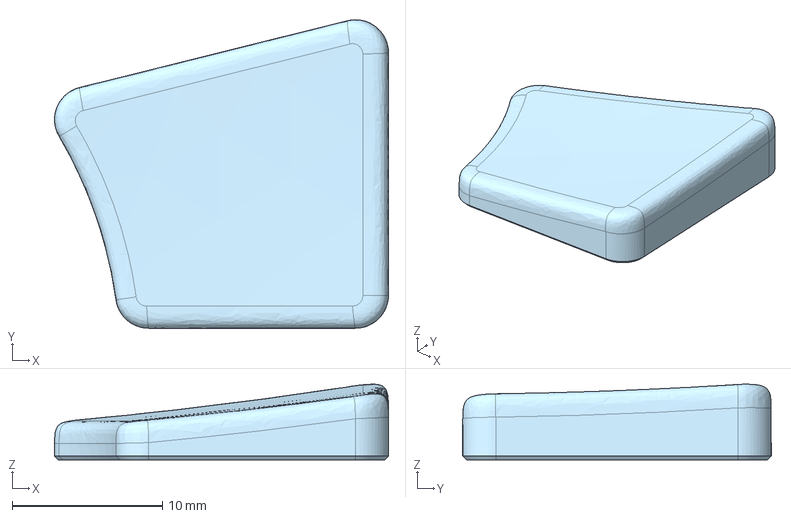
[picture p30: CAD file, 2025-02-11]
50-52.5mm ball/rev 2/raised-buttons/D650 Concave (experimental)/H1.2/Button 3.step
22.3 x 20.6 x 5.04 mm

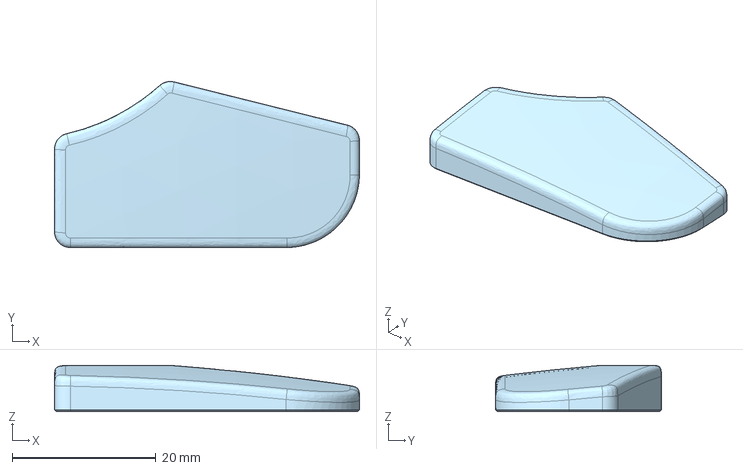
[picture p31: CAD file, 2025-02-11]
50-52.5mm ball/rev 2/raised-buttons/D700/H2.4/Adept 50-52mm rev2 - Button 5.step
42.4 x 23.1 x 6.46 mm

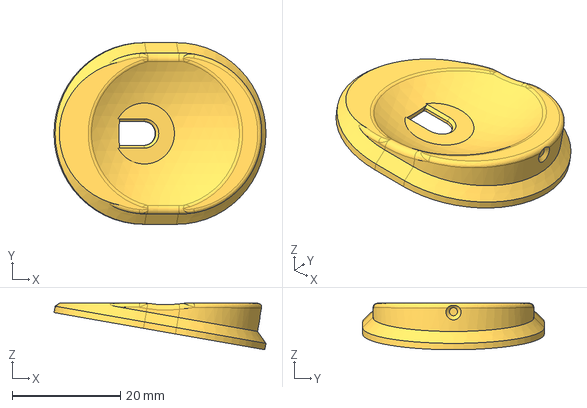
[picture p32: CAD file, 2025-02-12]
50-52.5mm ball/rev 2/sensor-cover/Sensor Cover.step
39.2 x 33.6 x 8.60 mm

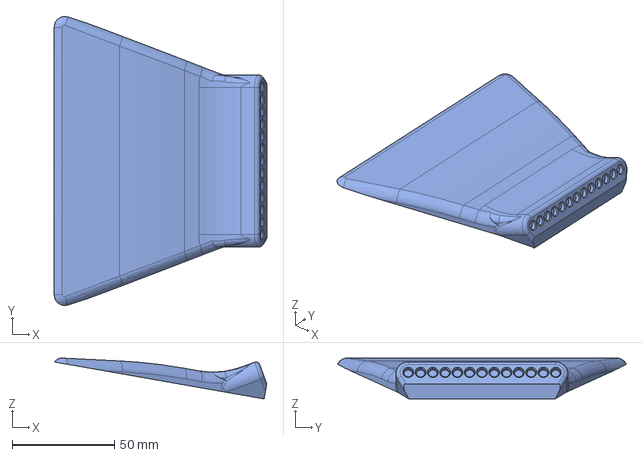
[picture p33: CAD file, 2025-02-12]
50-52.5mm ball/rev 2/wrist-rest/Low Wide.step
103.8 x 141.1 x 20.0 mm

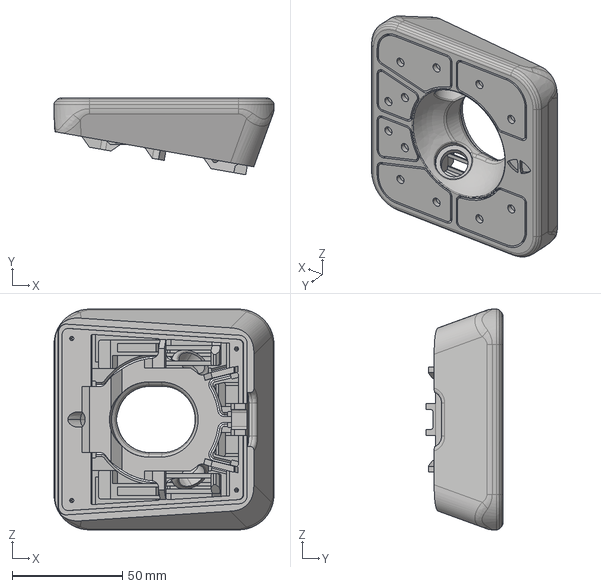
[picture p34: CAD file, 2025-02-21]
50-55mm ball (short version)/top-short-55mm-magnets.step
99.7 x 34.7 x 100.0 mm

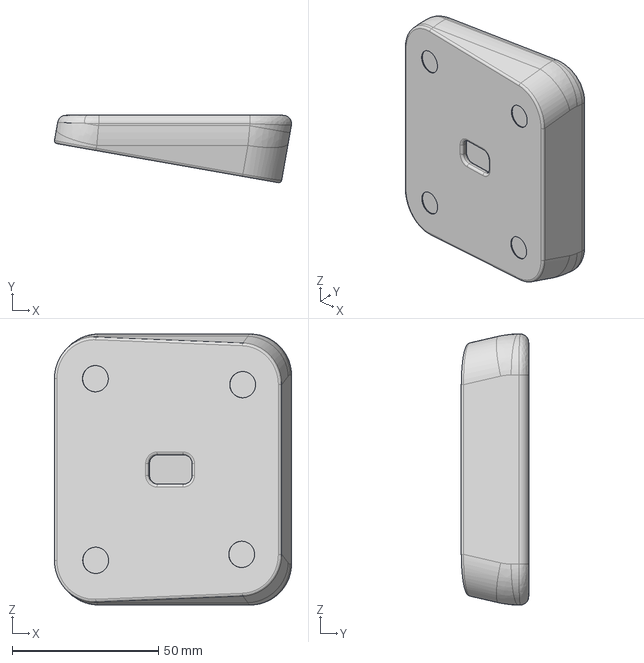
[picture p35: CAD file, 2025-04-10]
50-55mm ball (short, thin bezel)/STEP/palmrest for mjf hole.step
81.2 x 23.1 x 92.8 mm

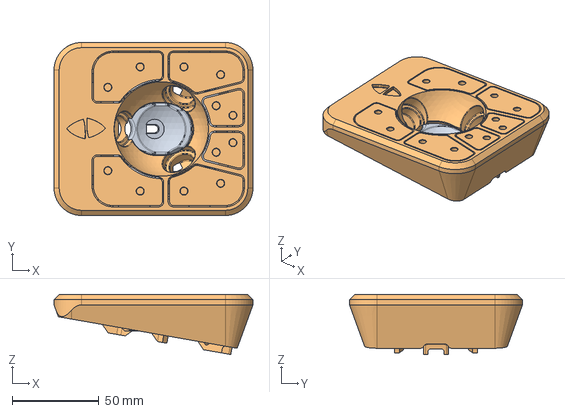
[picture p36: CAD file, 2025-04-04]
50-55mm ball/top-for-non-standard-SP8-BTUs.step
115.0 x 100.0 x 34.7 mm

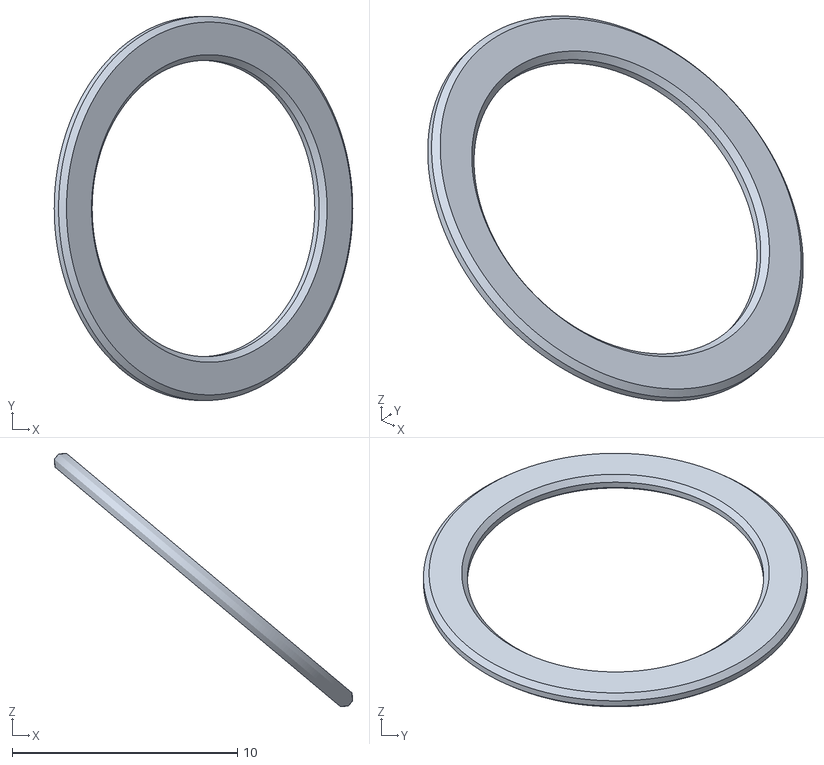
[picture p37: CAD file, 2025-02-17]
57-68mm ball (50-60mm with spacers)/btu-spacer/Spacer.stl
13.3 x 17.0 x 11.3

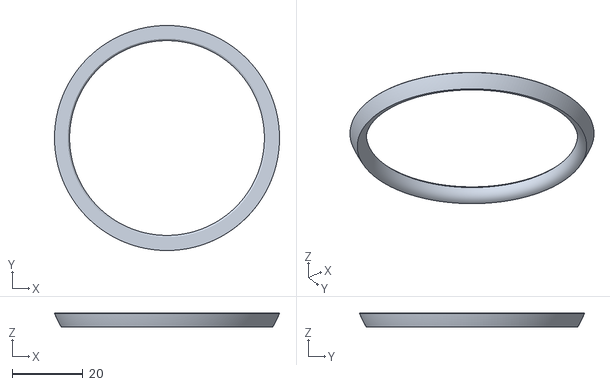
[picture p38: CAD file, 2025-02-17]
57-68mm ball (50-60mm with spacers)/insert/Insert.stl
63.5 x 63.5 x 3.97

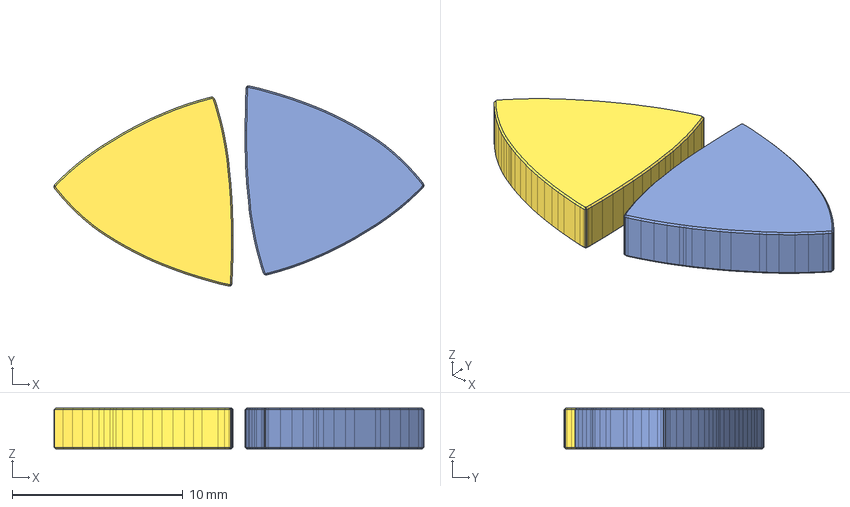
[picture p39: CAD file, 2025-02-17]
57-68mm ball (50-60mm with spacers)/Logo.step
21.7 x 11.7 x 2.40 mm

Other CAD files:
50-52.5mm ball/rev 2/Flat Sharp.step
adapters/Static-3mm-no-glue.step
buttons/default/D625/D625 H2.4.step
buttons/default/D750/D750 H1.2.step
44-45mm ball (+ short version)/short/bottom-short-303048-battery.step
44-45mm ball (+ short version)/short/bottom-short-battery.stl
44-45mm ball (+ short version)/short/bottom-short.step
44-45mm ball (+ short version)/short/top-short-45mm-magnets.step
44-45mm ball (+ short version)/short/top-short-45mm.step
44-45mm ball (+ short version)/short/top-short-battery.step
44-45mm ball (+ short version)/standard/top-45mm.step
50-52.5mm ball (deprecated)/rev 1/Adept 50mm Sharp.step
50-52.5mm ball (deprecated)/rev 1/Adept 50mm Smooth.step
50-52.5mm ball (deprecated)/rev 2/Flat Sharp.step
50-52.5mm ball (deprecated)/rev 2/Flat Smooth.step
50-52.5mm ball (deprecated)/rev 2/Magnets Sharp.step
50-52.5mm ball (deprecated)/rev 2/Magnets Smooth.step
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

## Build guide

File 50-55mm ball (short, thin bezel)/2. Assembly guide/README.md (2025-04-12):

## After Receiving the Package from JLC
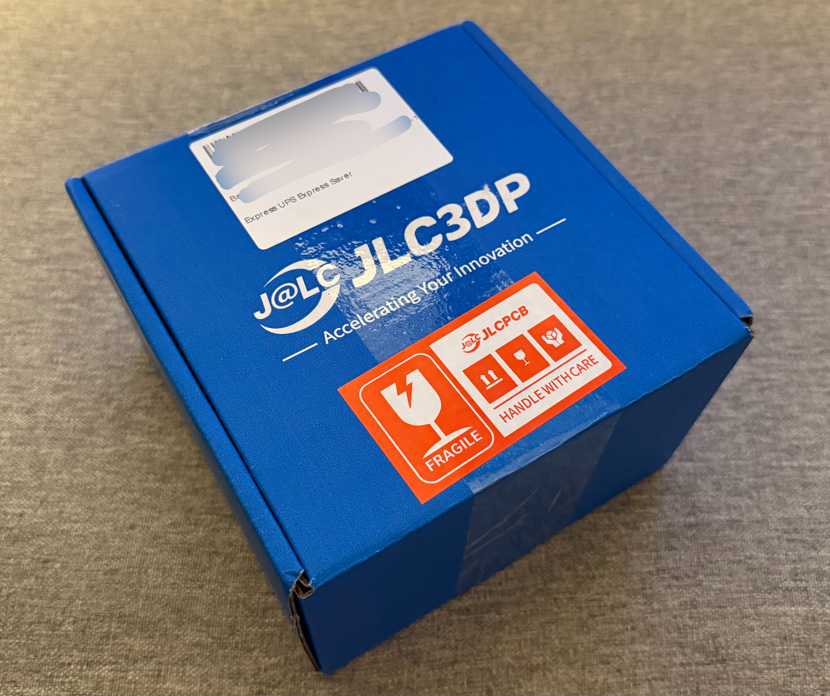
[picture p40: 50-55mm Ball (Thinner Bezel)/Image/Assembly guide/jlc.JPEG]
JLC Packaging


Once your parts arrive from JLC, check everything carefully.  
If any parts are missing or the surface finish has issues, file a quality complaint.  
In my experience, JLC's customer service has responded well in most cases their support is excellent.
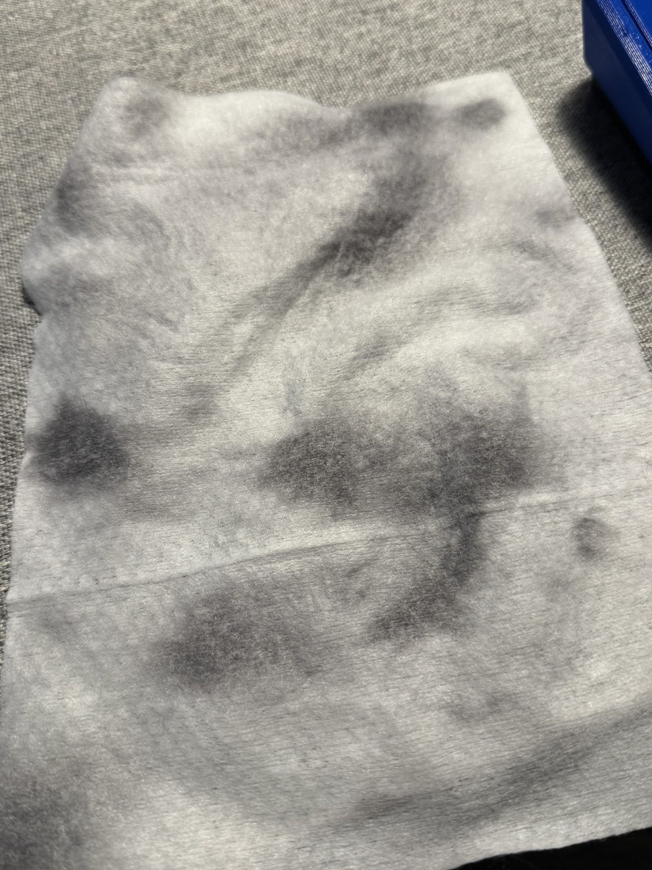
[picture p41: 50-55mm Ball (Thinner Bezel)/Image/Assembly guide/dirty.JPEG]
Surface Cleaning


Due to the MJF post-processing method, there may be some black powder residue on the surface.  
You can wipe it off or gently clean it using mild detergent.  
Although MJF prints are quite sturdy, be especially careful with the **top case spring structure**, which can be fragile.

## 1. Attach the Bumpers (If Needed)
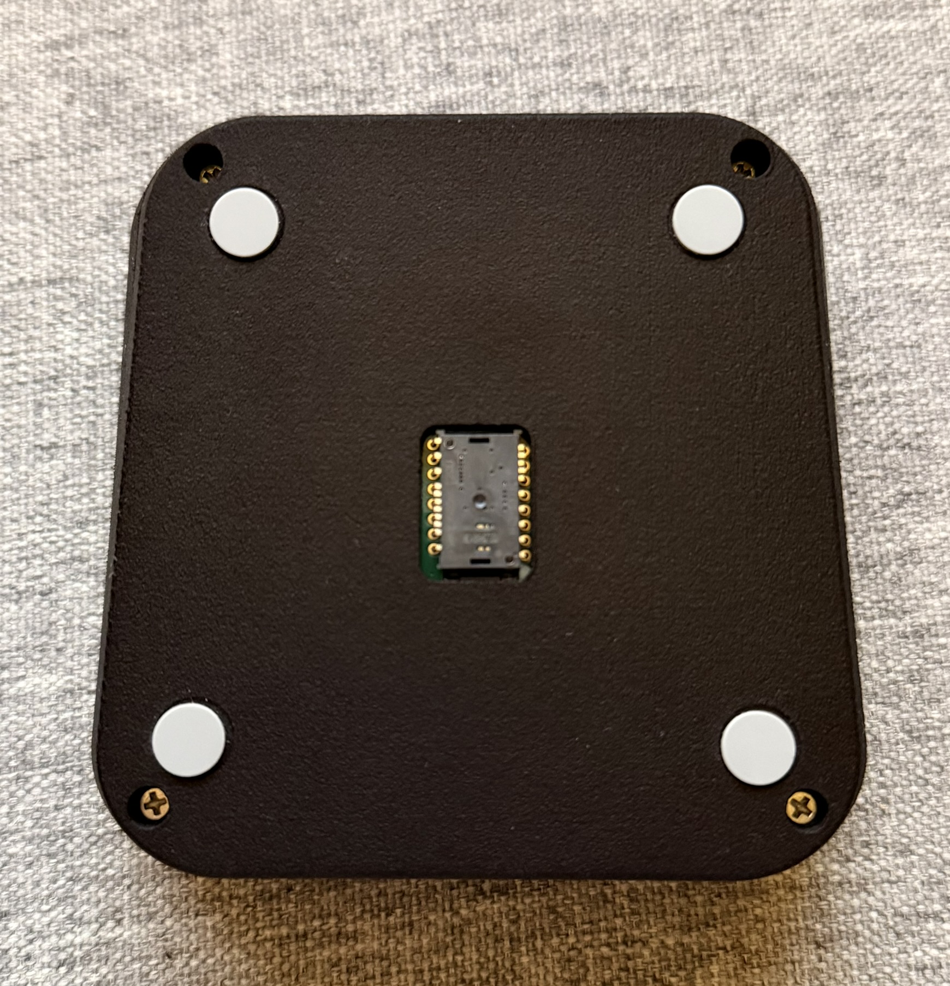
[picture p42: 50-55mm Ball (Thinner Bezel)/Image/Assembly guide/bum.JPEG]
Bumper Attachment


If you're using bumpers, attach them first.  
You could attach them later, but if you flip the case after installing the BTUs, BTUs may fall off and cause annoyance.

## 2. Insert the PCB into the Bottom Case
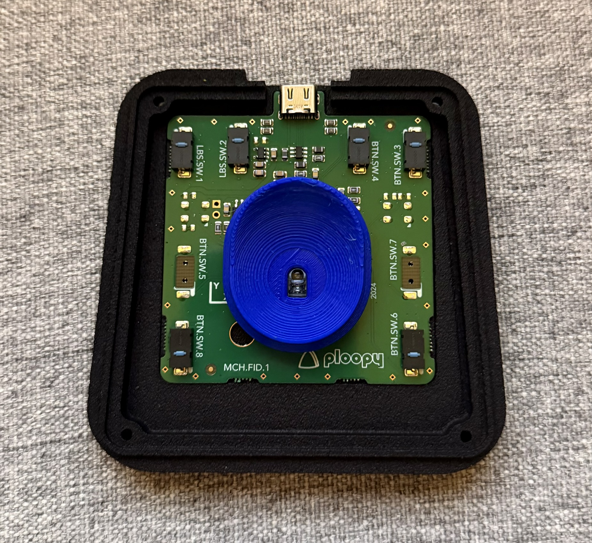
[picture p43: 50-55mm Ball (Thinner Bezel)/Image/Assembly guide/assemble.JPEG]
Case Assembly


Place the PCB into the bottom shell.  
The grooves are designed to align precisely, so it should fit easily.  
Then place the **sensor cover** on top of the PCB.

There is a hole at the bottom of the case to lower the overall height of the trackball.  
If you're worried about accidental liquid spills entering through this hole, it's recommended to cover it with tape for protection.

## 3. Assemble the Top Shell and Tighten Screws
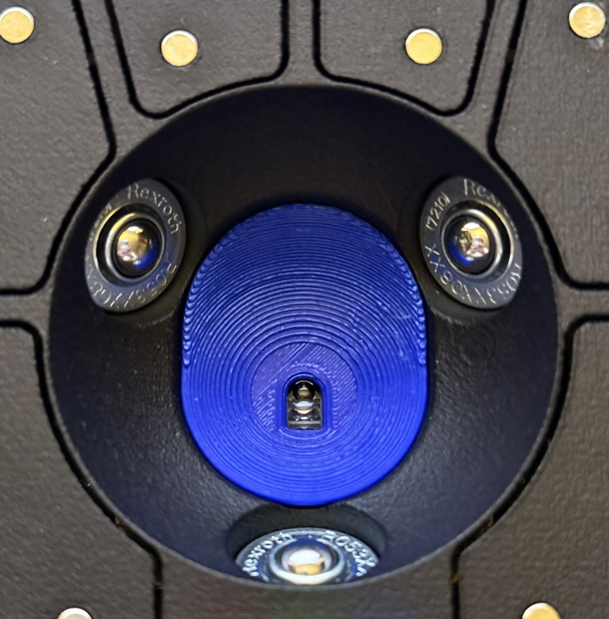
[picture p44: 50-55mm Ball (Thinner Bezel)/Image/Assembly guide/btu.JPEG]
BTU Installation


Combine the top shell and fasten the screws.  
You may not feel a tight grip. that’s okay. Gently try pulling the two halves apart.  
If they stay together, the fit is good enough.

At this point, **press all six buttons** to ensure they actuate correctly.  
Sometimes, due to slight 3D printing tolerances, a button might be constantly pressed.  
In that case, **slightly file down** the point of contact. Just a little will do.

Once all 6 buttons work fine, insert the **BTUs**.  
Depending on the print tolerance, the BTUs may slide in easily or feel tight.  
I printed this mod twice, and both had different BTU fitment.

If too tight, don't worry — you can **push the BTUs out from underneath** using a stick through the bottom of the top case.

## 4. Attach the Magnets
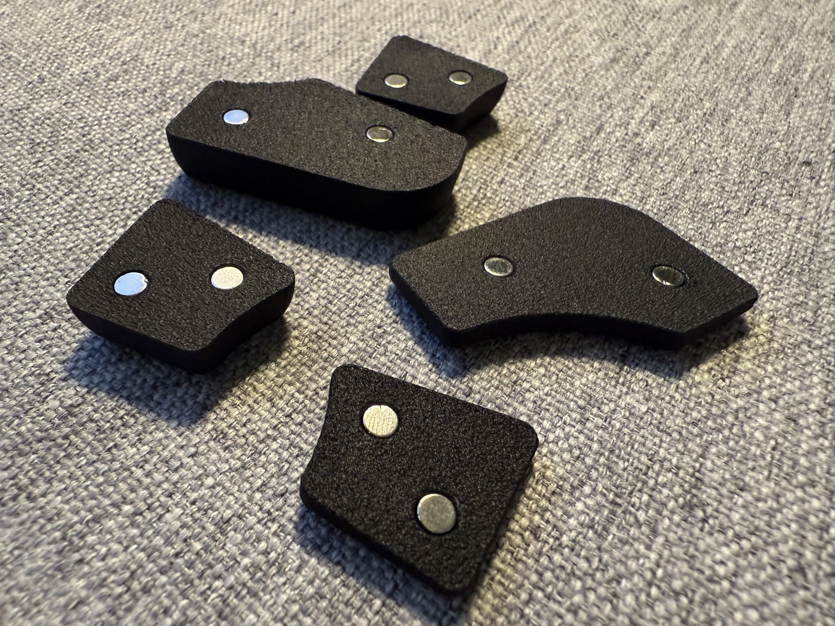
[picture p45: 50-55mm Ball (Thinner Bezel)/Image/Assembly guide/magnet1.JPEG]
Magnet Attachment - Step 1


This part can be nerve-wracking at first.  
To practice, **start with the button magnets**, as they're cheaper and easier to reprint if mistakes happen.

⚠️ Make sure all magnets are installed with the **same polarity**.  
This step is critical for the next step to work properly.

Also, ensure the magnets are **flush and not sticking out**.
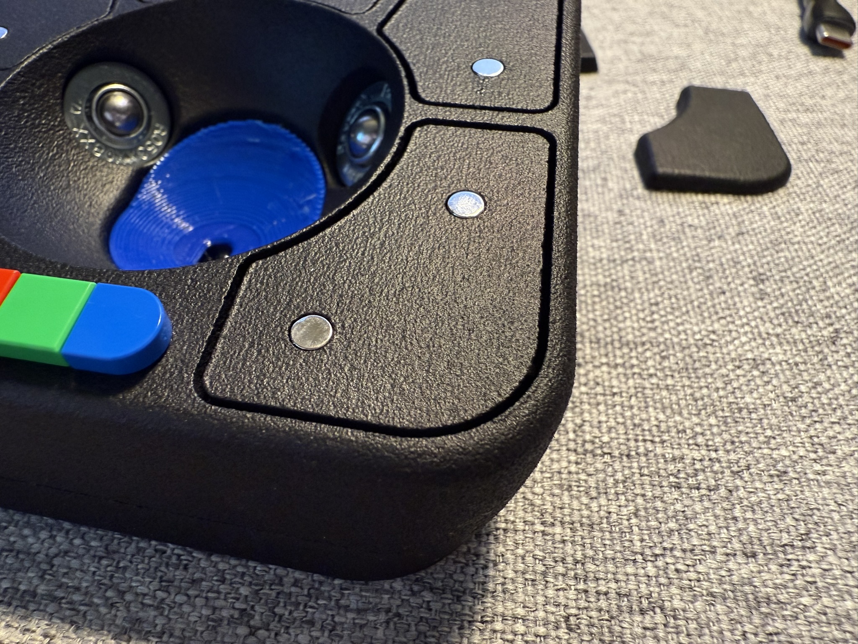
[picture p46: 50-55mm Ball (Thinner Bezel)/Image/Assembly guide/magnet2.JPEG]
Magnet Attachment - Step 2


After attaching magnets to the buttons, move on to the case.  
Since the buttons will stick to the case, you need to attach the case magnets with **opposite polarity**.

If you accidentally attach the same polarity on both sides, the buttons will repel and not stick.

## 5. Place the Ball and Insert LEGO Brick
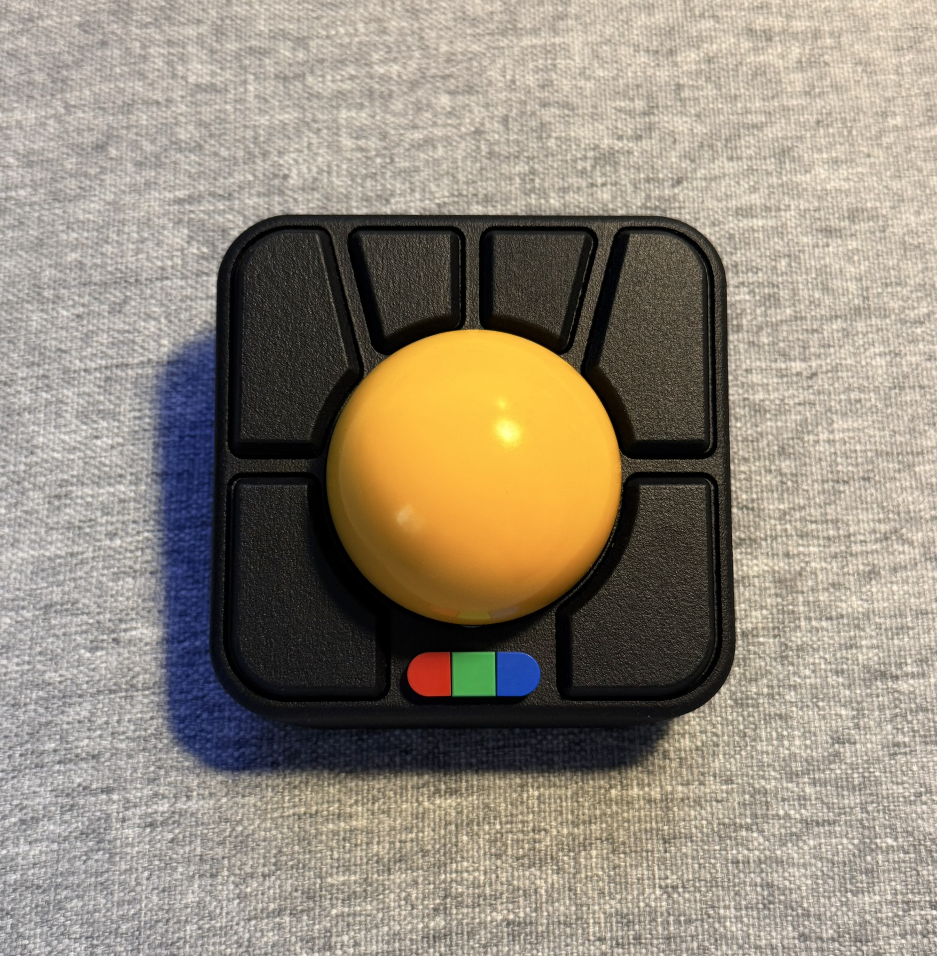
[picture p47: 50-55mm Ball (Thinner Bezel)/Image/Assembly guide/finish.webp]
Final Assembly


Place the trackball into the BTUs, and fit an appropriate LEGO brick into the 6 o’clock position.  
Then, upload your VIA or Vial firmware and start using the device.

At first, it may feel **extremely smooth**, making fine control difficult.  
That’s okay with a bit of practice, you’ll get used to it.

---

Wishing you a successful assembly!  
Thank you 🙏

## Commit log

2025-02-02 chore: initial commit
    [Adept Top w- BTUs.step]
2025-02-02 feat: 44mm ball support
    [Adept Top w- BTUs.step]
2025-02-05 feat: BTU extraction hole, STL
    [Adept Top w- BTUs.step]
2025-02-05 feat: better 44mm ball support
    [Adept Top w- BTUs.step]
2025-02-07 feat: 55mm ball mod
    [Adept 50mm Sharp.step, Adept 50mm Smooth.step, Adept.step]
2025-02-07 chore: rename
    [Adept Default.step]
2025-02-09 feat: better 45mm ball support
2025-02-10 chore: restructuring
    [Adept 50mm Sharp.step, Adept 50mm Smooth.step, Adept Top.step]
2025-02-11 feat: 50-52.4mm ball rev2
    [Adept Top.step, Bottom.step, Flat Sharp.step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]
2025-02-11 feat: different buttons
    [Adept 50-52mm rev2 - Button 1.step, Adept 50-52mm rev2 - Button 2.step, Adept 50-52mm rev2 - Button 3.step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]
2025-02-11 feat: concave buttons
    [Button 1.step, Button 2.step, Button 3.step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]
2025-02-11 feat: sensor cover improvement
    [Sensor Cover.step]
2025-02-11 bugfix: hotfix
    [Sensor Cover.step]
2025-02-12 feat: better tolerances
    [Flat Sharp.step, Flat Smooth.step, Magnets Sharp.step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]
2025-02-12 feat: better sensor cover
    [Sensor Cover.step]
2025-02-12 feat: wrist rest
    [Low Wide.step]
2025-02-12 bugfix: bottom part hotfix
    [Bottom.step]
2025-02-14 feat: update 45mm ball models and README
    [Adept Top.step, top-45mm-magnets.step, top-45mm.step]
2025-02-14 feat: rename folder and add images
    [top-45mm-magnets.step, top-45mm.step]
2025-02-16 feat: add short mod
    - add short mod
    - reorganize 44-45mm ball folder
    - create a folder for buttons following the standard
    - add spherical buttons
    [bottom-short-45mm.step, bottom-short-45mm.stl, spherical-buttons-5mm.step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]
2025-02-16 chore: buttons readme
2025-02-17 feat: 57-68mm ball mod files
    [Button 1.step, Button 2.step, Button 3.step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]
2025-02-17 feat: spacers for 50-60mm ball support
    [Button 1.step, Button 2.step, Button 3.step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]
2025-02-17 feat: better logo model
    [Logo Bottom.step, Logo Bottom.stl, Logo Top.step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]
2025-02-17 feat: insert
    [Insert.stl]
2025-02-18 feat: 50-57mm ball configuration
2025-02-18 feat: new buttons
    [Button 1.step, Button 2.step, Button 3.step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]
2025-02-18 feat: logo step (what r u doin step-logo??)
    [Logo (Full).step]
2025-02-18 feat: logo DXF
    [Logo (Full).dxf]
2025-02-21 feat: add 55mm short mod
    [bottom-short-45mm.step, bottom-short-45mm.stl, bottom-short.step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]
2025-02-21 chore: dirs rename
    [bottom-short.step, bottom-short.stl, logo-insert-short.step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]
2025-02-21 feat: veichu-to-rexroth adapter
    [Logo (Full).dxf, Logo (Full).step, Veichu-to-Rexroth Adapter.step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]
2025-02-22 feat: ISO-2025EFOG buttons
    [D625 H2.4.step, D625 H3.6.step, D750 H1.2.step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]
2025-02-22 fix: add .gitignore and remove faulty stl so I can add a new
2025-02-22 feat: add new stl to top-short-55mm-magnets
2025-02-22 feat: add 5mm flat buttons
    [flat-buttons-5mm.step]
2025-02-23 feat: replace 50-57mm shell with new 50-55mm version
    [Everything.step]
2025-02-23 chore: deprecate 50-52.5mm shell
    [Adept 50-52mm rev2 - Button 1.step, Adept 50-52mm rev2 - Button 2.step, Adept 50-52mm rev2 - Button 3.step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]
2025-02-23 chore: refactoring
    [Everything.3mf]
2025-02-23 chore: rename 55mm short folder and update readme files
    Reflecting that the short mod works with 50-55mm balls
    [bottom-short.step, bottom-short.stl, logo-insert-short.step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]
2025-02-23 feat: spacers
    [Spacer 0.4mm.step, Spacer 0.8 mm.step, Spacer 1.2mm.step]
2025-02-24 feat: better adapter
    [Veichu-to-Rexroth Adapter.step]
2025-02-24 feat: update top-short-45mm
    [top-short-45mm-magnets.step, top-short-45mm.step]
2025-02-24 feat: add bottom short with a cutout for a 303048 battery
    [bottom-short-303048-battery.step]
2025-02-27 feat: 50-55mm shell for SP-8 BTUs
2025-03-15 feat: 50-55mm shell for Veichu 15mm BTUs
    [top-for-non-standard-Veichu15-BTUs.step]
2025-03-17 feat: adapter for static bearings
    [Static-3to3.5mm.step, Veichu7.5.step]
2025-04-03 feat: step file for SP-8 shell
    [top-for-non-standard-SP8-BTUs.step]
2025-04-04 feat: better SP-8 shell tolerances
    [top-for-non-standard-SP8-BTUs.step]
2025-04-12 feat: assembly guide for the thin bezel shell
2025-04-14 feat: adapter for MR63 ball bearings
    [MR63-ball-bearings.step]
2025-04-17 feat: add static 2.5mm adapter and update docs
    [Static-2.5mm.3mf, Static-2.5mm.step]
2025-04-21 feat: add adapter to 3.5mm static bearings
    [Static-2.5mm-no-glue.3mf, Static-2.5mm-no-glue.step, Static-3.5mm-no-glue.step]
2025-04-21 feat: add 3mm static bearing adapter
    [Static-3mm-no-glue.step]
2025-05-06 feat: STL for spacers
    [Spacer 0.4mm.stl, Spacer 0.8mm.stl, Spacer 1.2mm.stl]
2025-05-20 feat: update files for the 45mm standard case with magnet holes
    [top-45mm-magnets.step]
2025-08-10 added adeptBLE short body for 44-45mm
    [bottom-short-battery.step, bottom-short-battery.stl, top-short-battery.step]
2025-08-10 forgot the switch plate.
    [bottom-short-battery.step, bottom-short-battery.stl]
